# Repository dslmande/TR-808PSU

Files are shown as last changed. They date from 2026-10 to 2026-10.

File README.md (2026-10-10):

# TR-808PSU

> ## ⚠️ UNTESTED
>
> **This board has not been manufactured, assembled or tested.** It has not been checked
> against the real unit, and it has not been tested against any safety standard. The design
> is a copy of a historical (1984–86) circuit board. It is connected to **mains voltage
> (230 V, or 110 V for the second variant)**, which can kill. Use at your own risk, and only if you know what you are doing.
> Dimensions are derived from a scan (±3 %), see [VERIFICATION.md](VERIFICATION.md).

KiCad rebuild of the power supply board **PS3116 (PCB 291-405A)** of the Roland TR-808:
schematic redrawn from the 1981 service manual, board with outline, holes, terminals and
component positions taken from the original component layout. Two variants of the same board:

| Variant | Original board | Mains | Transformer | Files |
|---|---|---|---|---|
| **230 V** | PS3116-054 | 220/240 V | N-219D | `TR-808PSU_Rev0.5*` |
| **110 V** | PS3116-051 | 100/117 V (built for 110 V, 117 V tap) | N-218C | `TR-808PSU_Rev0.5-110V*` |

Both use the same copper; they differ in parts (fuses, transformer, switch, C1) and in the
silkscreen mark (`PS3116-054  230V` / `PS3116-051  110V`), so the boards cannot be mixed up.
Current version: **Rev0.5**.

| Version | Contents |
|---|---|
| [Rev0.1](https://github.com/dslmande/TR-808PSU/releases/tag/Rev0.1) | historical 1:1 copy of the 1984–86 original; switched mains conductors SW_A/SW_B 3.75 mm apart |
| [Rev0.2](https://github.com/dslmande/TR-808PSU/releases/tag/Rev0.2) | as Rev0.1, but SW_B moved away on the mains side: SW_A/SW_B at least 5.67 mm apart |
| [Rev0.3](https://github.com/dslmande/TR-808PSU/releases/tag/Rev0.3) | as Rev0.2, but the 230 V primary side (terminals 1–9: mains, switch, transformer input) uses **RM5.0 screw terminals** (Phoenix MKDS 1,5) instead of solder lugs; terminals 10–22 (low voltage) stay solder lugs |
| [Rev0.4](https://github.com/dslmande/TR-808PSU/releases/tag/Rev0.4) / [Rev0.4-110V](https://github.com/dslmande/TR-808PSU/releases/tag/Rev0.4-110V) | as Rev0.3, but all board corners rounded to R5 (house rule), voltage mark on the silkscreen; the 110 V variant is new (fuses 0.5 A, transformer N-218C) |
| **Rev0.5** / **Rev0.5-110V** (current) | as Rev0.4, but the voltage mark moved to the free area below the fuse holders (it touched the F4 outline). Two releases: 230 V and 110 V |

## Pictures (230 V)

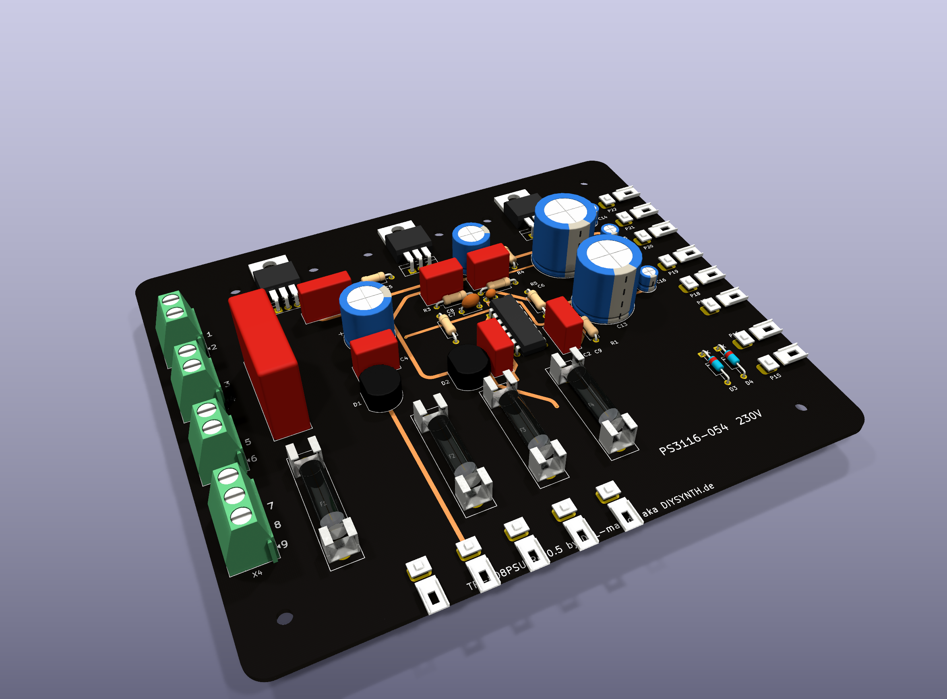
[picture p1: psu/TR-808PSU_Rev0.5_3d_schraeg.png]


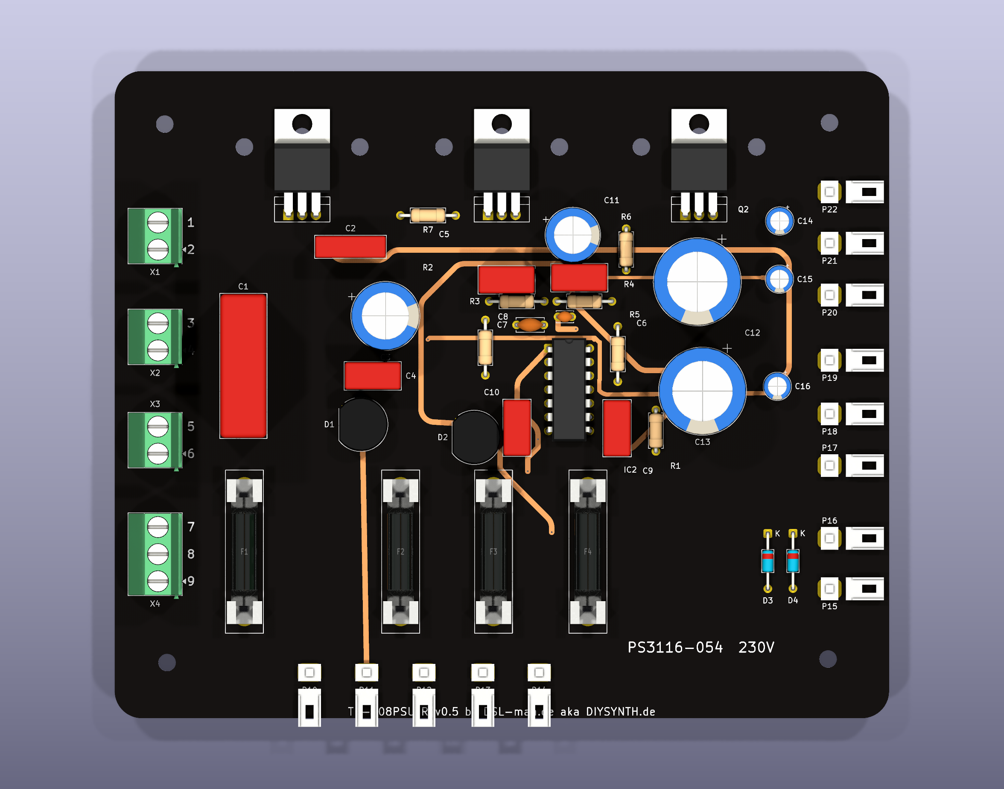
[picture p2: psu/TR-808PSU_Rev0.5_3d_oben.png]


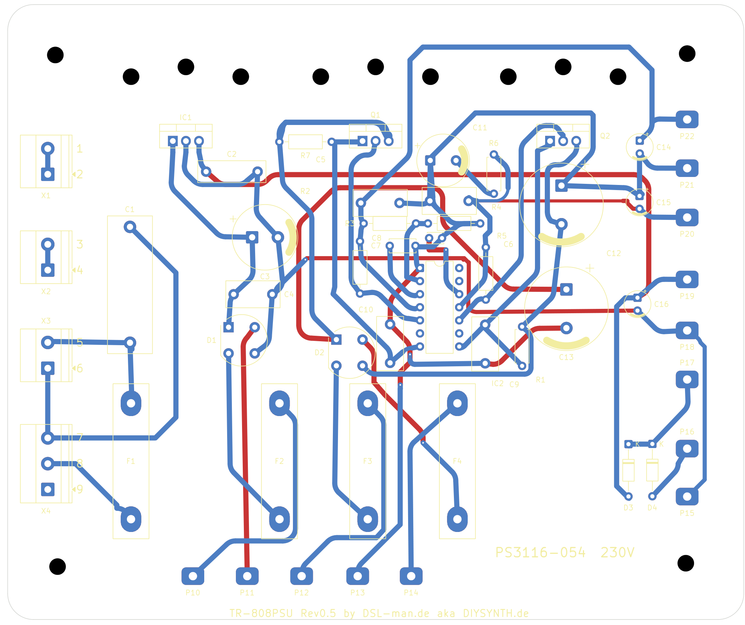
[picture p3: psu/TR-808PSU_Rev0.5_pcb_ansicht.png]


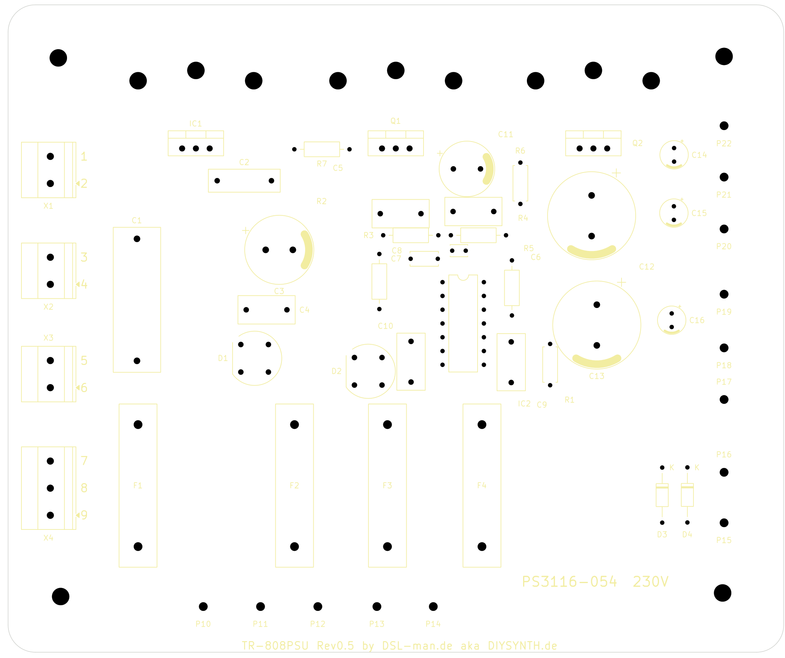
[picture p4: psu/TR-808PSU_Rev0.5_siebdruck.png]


### 110 V variant

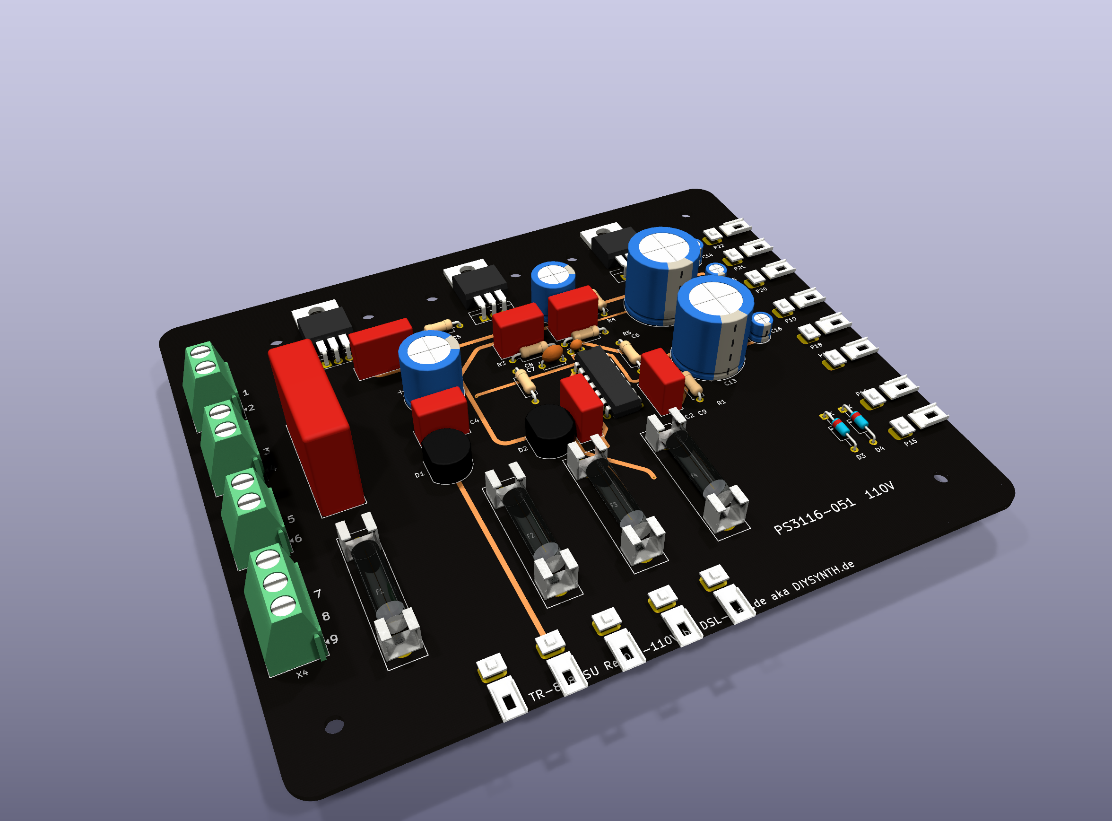
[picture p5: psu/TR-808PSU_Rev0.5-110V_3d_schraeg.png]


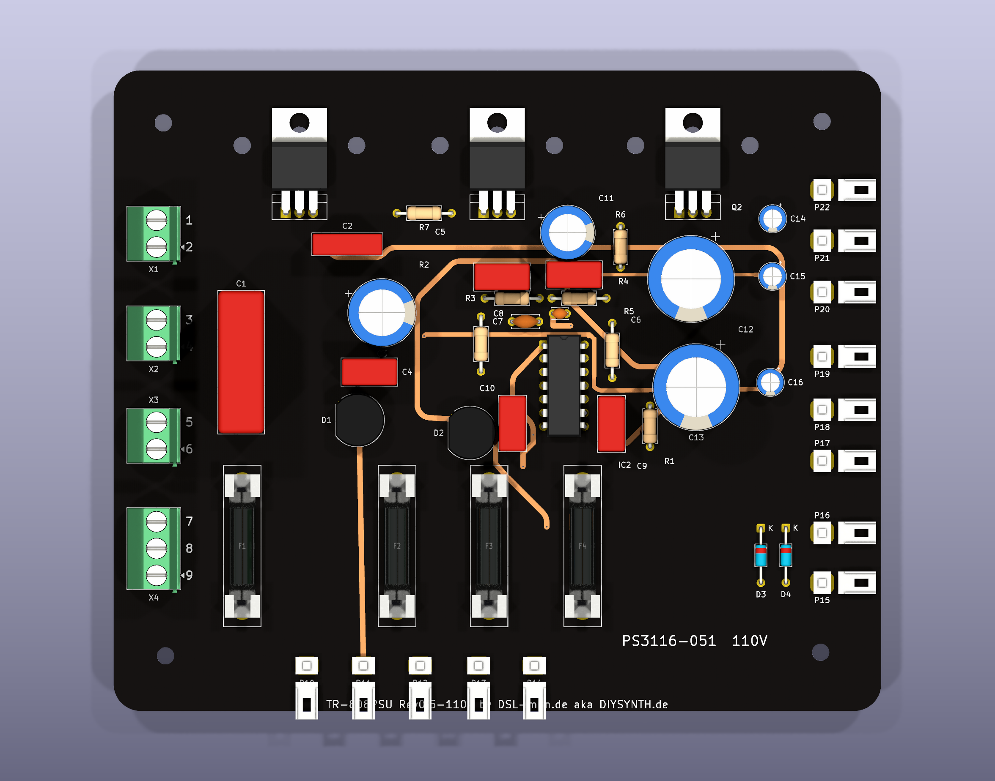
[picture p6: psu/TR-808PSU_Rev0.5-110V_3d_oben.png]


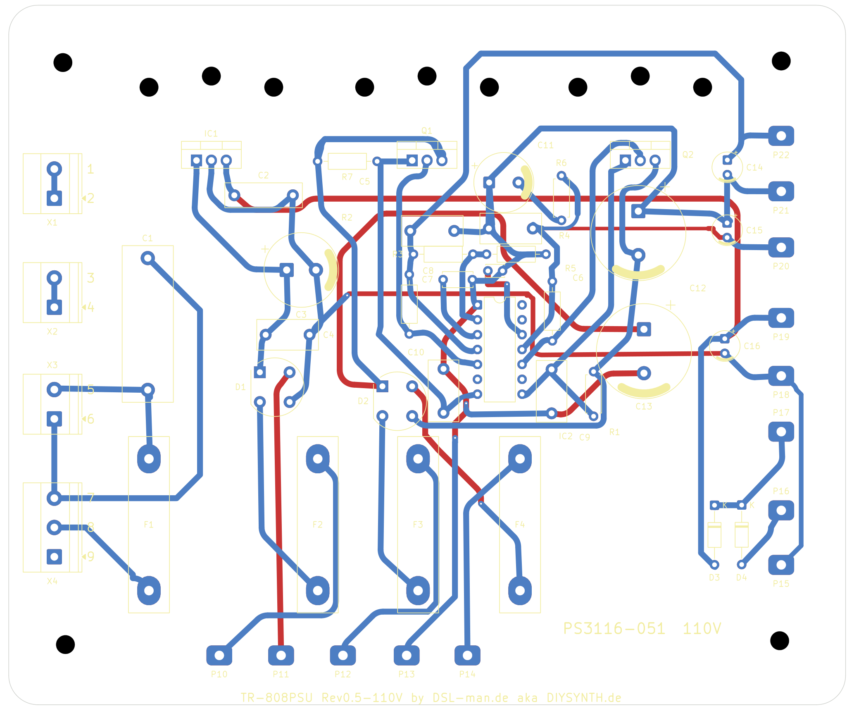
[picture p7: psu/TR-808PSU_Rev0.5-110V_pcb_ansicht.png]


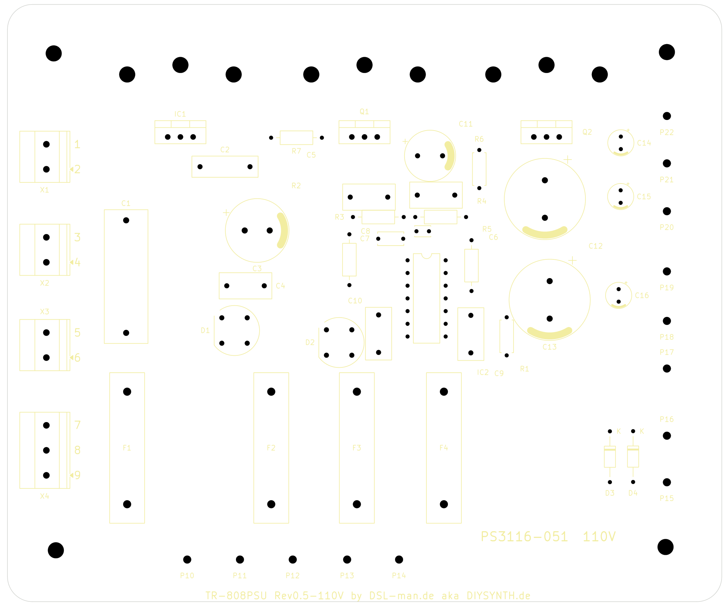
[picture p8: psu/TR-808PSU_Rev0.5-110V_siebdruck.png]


More (230 V; for 110 V use the `Rev0.5-110V` files, [BOM-110V.md](BOM-110V.md)): [schematic (PDF)](psu/TR-808PSU_Rev0.5_schaltplan.pdf) · [bill of materials](BOM.md) ([CSV](psu/TR-808PSU_Rev0.5_bom.csv)) · [1:1 printout (A4)](psu/TR-808PSU_Rev0.5_ausdruck_1zu1.pdf) · [Gerber (zip)](psu/TR-808PSU_Rev0.5_gerber.zip) · [assembly drawing (PDF)](psu/TR-808PSU_Rev0.5_assembly.pdf) · [original copper vs. tracks](psu/TR-808PSU_Rev0.5_ueberlagerung.png) · [verification](VERIFICATION.md) · [releases](https://github.com/dslmande/TR-808PSU/releases)

## Files

| File | Contents |
|---|---|
| [ORIGINAL.md](ORIGINAL.md) | source, manual pages, variants, circuit description, open points |
| [VERIFICATION.md](VERIFICATION.md) | standards context (DIN EN IEC 62368-1, IEC 60664-1), verification, validation, findings, risks |
| [BOM.md](BOM.md) / [BOM-110V.md](BOM-110V.md), `psu/TR-808PSU_Rev0.5_bom.csv` | bill of materials (readable, with function and original parts; CSV) |
| `psu/TR-808PSU_Rev0.5.kicad_pro` / `.kicad_sch` / `.kicad_pcb` (and `…Rev0.5-110V…`) | KiCad project |
| `psu/TR-808PSU_Rev0.5_schaltplan.pdf` | schematic plot |
| `psu/gerber_TR-808PSU_Rev0.5/`, `psu/TR-808PSU_Rev0.5_gerber.zip` | Gerber, drill data, position file |
| `psu/TR-808PSU_Rev0.5_ausdruck_1zu1.pdf` | 1:1 printout on A4 landscape: component side, solder side, drill template (print at 100 %, check the measuring bar) |
| `psu/TR-808PSU_Rev0.5_3d_oben.png`, `_3d_schraeg.png` | 3D views (KiCad ray tracing; own models for fuse holders and terminal lugs) |
| `psu/TR-808PSU_Rev0.5_pcb_top.pdf`, `_pcb_bottom.pdf`, `_assembly.pdf` | board plots |
| `psu/placement.json`, `psu/placement_scan.json` | component positions from the component layout, resp. aligned to the scan (mm) |
| `psu/kupfer.npz`, `psu/leitkarte.npz` | copper mask and net regions of the original (from the scan) |
| `psu/TR-808PSU_Rev0.5_ueberlagerung.png` | original copper against the tracks of this board |

File names with `schaltplan`, `ausdruck`, `kupfer` and `leitkarte` are German for schematic, printout, copper and guide map.

## What "1:1" means here

* **Circuit:** designators (C1–C16, R1–R7, D1–D4, F1–F4, Q1, Q2, IC1, IC2), values and
  terminal numbers 1–22 as in the original. The schematic is drawn like the original
  (mains and switch left, transformer, +5 V branch, ±15 V branch).
* **Board:** outline (from Rev0.5 with R5 corners instead of the sharp corners of the original), four mounting holes, six heat sink holes (one pair per regulator,
  21.3 mm apart, centred) and three M3 screw holes for the regulators, RM5 screw terminals
  (terminals 1–9), terminal pins (10–22), fuse clips and all components at the positions of
  the original, fine-tuned to the copper of the scan. The original is single
  sided with one wire jumper; this rebuild is two-layer.
* **Tracks: guided by the original, not copied one to one.** The copper of the original is
  extracted from the scan (halftone → mask → net regions) and used as a cost map by the
  router: original copper is cheap, everything else is expensive, the component side is
  almost blocked. The result is a DRC-clean board that follows the original where the scan
  allows. **37 % of the track length lies on original copper**, the rest is routed anew
  (wide tracks and smoothing move the paths away from the original);
  `psu/TR-808PSU_Rev0.5_ueberlagerung.png` shows the original copper (grey) and the tracks
  (red solder side, blue component side). Pure tracing without the router fails because of
  the scan quality (shorts between neighbouring tracks, pad positions only within ±0.3 mm).
* **Dimensions** are derived from the component layout (the manual has no scale), tolerance
  about ±3 %. Measure against a real board before manufacturing. Details and further open
  points in [ORIGINAL.md](ORIGINAL.md).

## Status (Rev0.5, 10 Oct 2026; both variants)

* **ERC:** 0 violations (`psu/TR-808PSU_Rev0.5-erc.rpt`).
* **DRC (clearance rule 0.25 mm):** 0 errors; warnings only (4 courtyard overlaps, 1
  silkscreen overlap, 7 footprint deviations from the library because of the polarity bars);
  0 unconnected items; schematic/board parity 0.
* **Mains against low voltage:** more than 8 mm copper to copper;
  between the mains conductors 4.0–5.67 mm, adjacent terminal poles 2.4 mm (RM5 pitch).
* **Netlist against the schematic:** read by hand from the schematic and checked against the
  plot; no independent comparison, see "Open" in [ORIGINAL.md](ORIGINAL.md).
* Track width 1.0 mm throughout; hairpins and stubs in pads are
  removed; smoothed (45°, arcs). No copper pours, as in the original. Five
  vias; most of the copper is on the solder side, about 440 mm of track on the component side
  (the original used the wire jumper J1 for this).
* **Silkscreen:** designators only (no values), terminal numbers 1–9 next to the screw
  terminals and P10–P22 on the pins, electrolytic polarity as a bar at the minus side as in
  the original, the four fuse holders F1–F4 on one line.
* **Not done:** assembly and measurement on the unit, manufacturing, any safety testing.

## Rebuilding

Schematic and layout were generated with a private tool chain that is not part of this
repo. The KiCad project in `psu/` is complete and needs only KiCad 9/10.

## License

Hardware files (KiCad project, Gerber, schematic, documents):
[CERN-OHL-W-2.0](LICENSE) (CERN Open Hardware Licence v2, weakly reciprocal). The licence
covers only this redrawing and layout, not Roland's original design or manual. Provided as is, without
warranty: see the disclaimer in the licence and the UNTESTED notice above.

## Source and rights

Circuit and dimensions come from the Roland TR-808 service manual (15 June 1981). The manual
itself and the data sheets are not part of this repo (copyright of Roland and the
manufacturers). This repo contains an own redrawing for repair and rebuild. "Roland" and
"TR-808" are trademarks of Roland Corporation; this project is not affiliated with Roland.

Data sheets used to check the pin assignments: 2SB596 (MOSPEC), 2SD880 (DC Components),
TA7179P and µA7805 (service manual, page 2).

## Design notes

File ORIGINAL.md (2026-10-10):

# The original: power supply board PS3116 of the Roland TR-808

> **UNTESTED.** This describes how the rebuild relates to the original; nothing here was
> verified on a real unit. See [VERIFICATION.md](VERIFICATION.md).

Source is the service manual "TR-808 Service Notes" (Roland, 15 June 1981, 3rd printing),
archive.org scan `Roland_TR-808_Service_Manual.pdf` (MD5 `77ac6c77c9e0d92ea67b2021ecc97623`,
16 pages). The manual is not part of this repo; to check the work, download it yourself and
put it under `vorlage/` (German for "template"; excluded there by `.gitignore`).

| Sheet | Contents | Used for |
|---|---|---|
| 2 | pin assignments (TA7179P, µA7805) | symbols IC2, IC1 |
| 10 | parts list | component types, board numbers |
| 12 | component layout POWER SUPPLY PS3116-051/-054, PCB 291-405A | board outline, component positions |
| 13 | schematic (top left: POWER SUPPLY) | schematic |
| 15 | design changes | read, does not concern the power supply |

## Variants

The board is the same for all mains voltages; only the fitting and accessories differ:

| Mains | Board | T1 | Switch | C1 | Fuses F1–F4 |
|---|---|---|---|---|---|
| 100 V | PS3116-051 | N-217N | SDG5P-001 | ECQ-UC1A473MC | SGA 0.5 A |
| 117 V | PS3116-051 | N-218C | SDG5P-001 | ECQ-UC1A473MC | SGA 0.5 A |
| 220 V | PS3116-054 | N-219D | SDG5P-502 | ECQ-U2A473MF | CEE 250 mAT |
| 240 V | PS3116-054 | N-219D | SDG5P-502 | ECQ-U2A473MF | CEE 250 mAT |

**This repo models both: the 220/240 V variant (PS3116-054, files `Rev0.5`) and, from Rev0.5,
the 100/117 V variant (PS3116-051) built for 110 V (files `Rev0.5-110V`, transformer N-218C,
117 V tap; 110 V is 6 % below its rating).** Only parts change (C1, F1–F4, T1, switch); the copper
is identical. The schematic of each variant carries its own values. According to the manual F2 and F3 are
fitted differently on late 100/117 V units; the note in the plan is hard to read at that
spot, see "Open".

## Circuit

* **Mains:** terminals 3 (W1) and 1 (W3) are the mains lead. 3 and 4, and 1 and 2, are
  connected on the board. The mains switch (two poles, not on the board) connects 4–5 and
  2–6. C1 (47 nF, interference suppression) sits between 5 and 6, F1 from the switch to
  terminal 8. T1 connects to 7, 8, 9 (primary) and 10–14 (secondary).
* **+5 V:** winding yellow–yellow (10, 11) → F2 → bridge D1 → C3 1000 µ/16, C4 100 n → IC1
  µA7805 → +5 V. C2 100 n and C16 10 µ at the output. Terminal 19 is +5 V, 15 and 18 are the
  5 V ground.
* **RAM backup:** D3 (1S2473) from +5 V, D4 (1S2473) from the 3 × 1.5 V battery (terminal 16,
  minus at 15), both cathodes to terminal 17.
* **±15 V:** winding red–black–red (12, 13 centre tap, 14) → F3/F4 → bridge D2 → C13, C12
  1000 µ/35 each → ±23 V. IC2 TA7179P (dual tracking regulator) with the pass transistors
  Q1 2SB596 (+) and Q2 2SD880 (−), a 47 Ω base resistor each (R7, R1) with 100 n (C10, C9),
  3.3 Ω current limit (R2, R5), divider R3/R4 15 k, C7/C8 10 n compensation. Outputs +15 V
  (22), 0 V (21), −15 V (20). C5, C14, C6, C15 smoothing, C11 470 µ/16 with R6 220 Ω as load.
* **Secondary voltages according to the plan at 0.15 A DC:** 10 V (yellow–yellow), 23 V per
  half (red–black).

## What the rebuild changes

* The original is **single sided** (wire jumper J1). This rebuild is **two-layer**, the
  jumper is dropped; board outline, holes, terminals and component positions follow the
  component layout and are adjusted to the scan copper; the tracks **follow the original
  copper only to 37 %** (router with a cost map from the scan, see the README), the rest is
  routed anew.
* The two grounds (5 V branch: terminals 15/18; ±15 V branch: 13/21) are **not** connected
  in the plan and are not connected here either. They meet only outside the board, probably
  on the main board.
* Transformer T1, mains switch and battery are not on the board (from Rev0.3 mains, switch
  and transformer input use RM5 screw terminals instead of solder lugs) and appear in the
  schematic only as external symbols.
* Bridges D1/D2: **W04** (400 V; the unit shows 2W04G) instead of W-02 (200 V) from the
  manual. The W04 is a permissible replacement in the same package.

## Open / not proven

* **Scale:** the component layout has no scale bar. The scale (0.544 mm per pt) is derived
  from the TO-220 lead pitch (2.54 mm) and the DIP-14; the board is 142.9 × 119.4 mm, with a
  tolerance of roughly ±3 %. Measure against a real board before manufacturing (holes of the
  heat sink 246-101A, distance of the fuse clips 22.5 mm).
* **Labelling in the component layout deviates from the schematic** at R1/R7 and C9/C10 (the
  assignment to Q1/Q2 is swapped). The netlist follows the schematic; the parts sit by
  function in the layout.
* **Lead spacing of the parts** (resistors, film capacitors) was chosen from the scan copper
  (pads must lie on copper pieces that carry only one net), not from the manual; four copper
  pieces still show a net conflict in the fit (AC15_A/AC15_RAW_A and others, probably
  connected copper because of the scan quality). The manual gives no package types.
* **Packages:** bridge as a round package ø 9.8 mm (Vishay WOG), electrolytics by measured
  diameter; the manual gives no package types.
* Pin assignment of 2SB596 / 2SD880: B-C-E (MOSPEC resp. DC Components data sheets, from
  archive.org/distributors, not in the repo).
* The footnote on the fuses ("F2–F3 on later 100/117V versions … 10 ohm 1/4W (fusing
  resistor)") is cut off in the scan and not clearly legible.

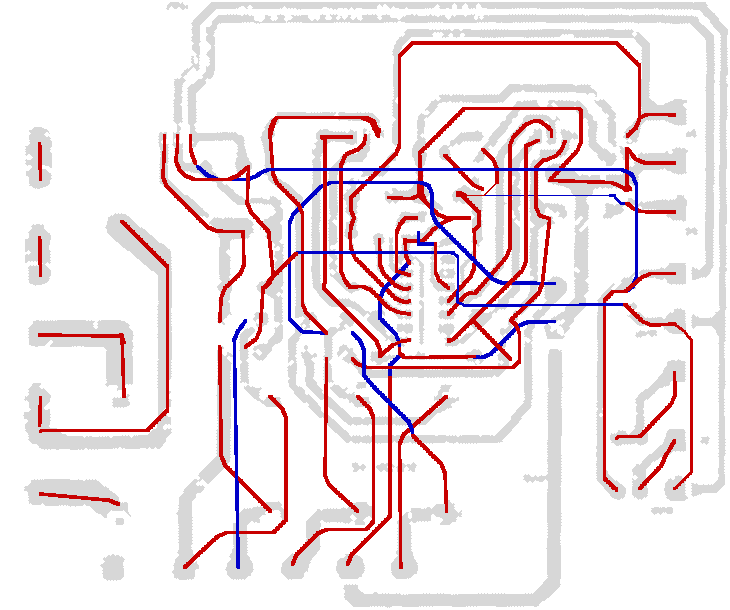
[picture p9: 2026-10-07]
psu/TR-808PSU_Rev0.5_ueberlagerung.png

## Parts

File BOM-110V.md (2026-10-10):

# Bill of materials TR-808PSU Rev0.5-110V

> **UNTESTED.** Nothing here has been ordered, built or measured.

Generated from the schematic (`psu/TR-808PSU_Rev0.5-110V_bom.csv`). **No prices, no suppliers:** none of that is checked.
Parts of the power supply per the service manual (PS3116-051, 100/117 V, built for 110 V); the "Remark" column names the original part where the manual gives one.

| Designators | Qty | Value | Function | Package (KiCad) | Remark |
|---|---|---|---|---|---|
| C1 | 1 | 0.047u/X2 | Interference suppression capacitor, 100/117 V | `C_Rect_L26.5mm_W8.5mm_P22.50mm_MKS4` | Original ECQ-UC1A473MC (Panasonic), 47 nF; 110 V: X2 type is also fine |
| C2 | 1 | 0.1u | Decoupling +5 V | `C_Rect_L13.0mm_W4.0mm_P10.00mm_FKS3_FKP3_MKS4` | 100 nF film |
| C3 | 1 | 1000u/16V | Smoothing 5 V branch | `CP_Radial_D12.5mm_P5.00mm` | 1000 µF / 16 V electrolytic |
| C4, C5, C6, C9, C10 | 5 | 0.1u | Decoupling / smoothing | `C_Rect_L10.3mm_W5.0mm_P7.50mm_MKS4` | 100 nF film, 7.5 mm pitch |
| C7 | 1 | 0.01u | Compensation TA7179P pin 3 | `C_Disc_D5.0mm_W2.5mm_P5.00mm` | 10 nF |
| C8 | 1 | 0.01u | Compensation TA7179P pin 12 | `C_Disc_D3.0mm_W2.0mm_P2.50mm` | 10 nF |
| C11 | 1 | 470u/16V | Load ±15 V with R6 | `CP_Radial_D10.0mm_P5.00mm` | 470 µF / 16 V electrolytic |
| C12, C13 | 2 | 1000u/35V | Smoothing ±23 V | `CP_Radial_D16.0mm_P7.50mm` | 1000 µF / 35 V electrolytic |
| C14, C15, C16 | 3 | 10u/16V | Output smoothing | `CP_Radial_D5.0mm_P2.50mm` | 10 µF / 16 V electrolytic |
| D1, D2 | 2 | W04 | Bridge rectifier, round | `Diode_Bridge_Round_D9.8mm` | Manual: W-02 (200 V); fitted/replacement: W04 (2W04G, 400 V) |
| D3, D4 | 2 | 1S2473 | RAM backup diodes | `D_DO-35_SOD27_P10.16mm_Horizontal` | 1S2473 (Si diode); replacement e.g. 1N4148 – not checked |
| F1, F2, F3, F4 | 4 | 0.5A | Miniature fuses 5×20 mm | `FuseClip_5x20_TF785` | SGA 0.5 A (100/117 V); clips TF785, 22.5 mm apart; fuse type per original, not checked |
| IC1 | 1 | uA7805 | 5 V regulator | `TO-220-3_Vertical` | µA7805UC, TO-220, lying on the heat sink angle |
| IC2 | 1 | TA7179P | Dual ±15 V tracking regulator | `DIP-14_W7.62mm` | TA7179P (Toshiba), DIP-14 – probably discontinued, availability not checked |
| P10 | 1 | 10 |  | `Terminal_Pin` |  |
| P11 | 1 | 11 |  | `Terminal_Pin` |  |
| P12 | 1 | 12 |  | `Terminal_Pin` |  |
| P13 | 1 | 13 |  | `Terminal_Pin` |  |
| P14 | 1 | 14 |  | `Terminal_Pin` |  |
| P15 | 1 | 15 |  | `Terminal_Pin` |  |
| P16 | 1 | 16 |  | `Terminal_Pin` |  |
| P17 | 1 | 17 |  | `Terminal_Pin` |  |
| P18 | 1 | 18 |  | `Terminal_Pin` |  |
| P19 | 1 | 19 |  | `Terminal_Pin` |  |
| P20 | 1 | 20 |  | `Terminal_Pin` |  |
| P21 | 1 | 21 |  | `Terminal_Pin` |  |
| P22 | 1 | 22 |  | `Terminal_Pin` |  |
| Q1 | 1 | 2SB596 | Pass transistor +15 V | `TO-220-3_Vertical` | 2SB596 (PNP, TO-220) |
| Q2 | 1 | 2SD880 | Pass transistor −15 V | `TO-220-3_Vertical` | 2SD880 (NPN, TO-220) |
| R1 | 1 | 47 | Base resistor Q2 | `R_Axial_DIN0207_L6.3mm_D2.5mm_P7.62mm_Horizontal` | 47 Ω |
| R2, R5 | 2 | 3.3 | Current limit | `R_Axial_DIN0207_L6.3mm_D2.5mm_P10.16mm_Horizontal` | 3.3 Ω |
| R3, R4 | 2 | 15k | Voltage divider | `R_Axial_DIN0207_L6.3mm_D2.5mm_P10.16mm_Horizontal` | 15 kΩ |
| R6 | 1 | 220 | Load ±15 V with C11 | `R_Axial_DIN0207_L6.3mm_D2.5mm_P7.62mm_Horizontal` | 220 Ω |
| R7 | 1 | 47 | Base resistor Q1 | `R_Axial_DIN0207_L6.3mm_D2.5mm_P10.16mm_Horizontal` | 47 Ω |
| X1, X2, X3 | 3 | 2P RM5 | Screw terminals mains (110 V), 2 poles | `TerminalBlock_Phoenix_MKDS-1,5-2_1x02_P5.00mm_Horizontal` | Phoenix MKDS 1,5/2-5,00 (5.0 mm pitch) |
| X4 | 1 | 3P RM5 | Screw terminal mains (110 V), 3 poles | `TerminalBlock_Phoenix_MKDS-1,5-3_1x03_P5.00mm_Horizontal` | Phoenix MKDS 1,5/3-5,00 (5.0 mm pitch) |
|  | 0 | solder lug | terminals 10–22 (low voltage) | `Terminal_Pin` (own design) | original: solder lugs; hole 1.6 mm, pad 4.4 × 3.4 mm |

## Not in the bill of materials (mechanical / external)

- **Mains transformer T1:** connected through terminals 7–9 (primary) and 10–14 (secondary); original N-218C (117 V), not on the board; 110 V is 6 % below its rating.
- **Mains switch SW1** (two poles, SDG5P-001 for 100/117 V) and **battery 3 × 1.5 V** (between 15 and 16): external.
- **Heat sink 246-101A** (aluminium angles, three pieces) with M3 screws: 6 holes for the angles plus three screw holes for the regulators.
- **Mounting:** four M3 holes at the board corners.

## Parts at risk

TA7179P, 2SB596, 2SD880 and the 1S2473 are early-1980s parts; with rebuilds of old units such types are often discontinued and affected by counterfeits. Before ordering, check them via the Mouser/TME API and settle a replacement for IC2 (see [VERIFICATION.md](VERIFICATION.md)).

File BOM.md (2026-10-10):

# Bill of materials TR-808PSU Rev0.5

> **UNTESTED.** Nothing here has been ordered, built or measured.

Generated from the schematic (`psu/TR-808PSU_Rev0.5_bom.csv`). **No prices, no suppliers:** none of that is checked.
Parts of the power supply per the service manual (PS3116-054, 220/240 V); the "Remark" column names the original part where the manual gives one.

| Designators | Qty | Value | Function | Package (KiCad) | Remark |
|---|---|---|---|---|---|
| C1 | 1 | 0.047u/X2 | Interference suppression capacitor X2, 220/240 V | `C_Rect_L26.5mm_W8.5mm_P22.50mm_MKS4` | Original ECQ-U2A473MF (Panasonic), 47 nF, 275 V~ |
| C2 | 1 | 0.1u | Decoupling +5 V | `C_Rect_L13.0mm_W4.0mm_P10.00mm_FKS3_FKP3_MKS4` | 100 nF film |
| C3 | 1 | 1000u/16V | Smoothing 5 V branch | `CP_Radial_D12.5mm_P5.00mm` | 1000 µF / 16 V electrolytic |
| C4, C5, C6, C9, C10 | 5 | 0.1u | Decoupling / smoothing | `C_Rect_L10.3mm_W5.0mm_P7.50mm_MKS4` | 100 nF film, 7.5 mm pitch |
| C7 | 1 | 0.01u | Compensation TA7179P pin 3 | `C_Disc_D5.0mm_W2.5mm_P5.00mm` | 10 nF |
| C8 | 1 | 0.01u | Compensation TA7179P pin 12 | `C_Disc_D3.0mm_W2.0mm_P2.50mm` | 10 nF |
| C11 | 1 | 470u/16V | Load ±15 V with R6 | `CP_Radial_D10.0mm_P5.00mm` | 470 µF / 16 V electrolytic |
| C12, C13 | 2 | 1000u/35V | Smoothing ±23 V | `CP_Radial_D16.0mm_P7.50mm` | 1000 µF / 35 V electrolytic |
| C14, C15, C16 | 3 | 10u/16V | Output smoothing | `CP_Radial_D5.0mm_P2.50mm` | 10 µF / 16 V electrolytic |
| D1, D2 | 2 | W04 | Bridge rectifier, round | `Diode_Bridge_Round_D9.8mm` | Manual: W-02 (200 V); fitted/replacement: W04 (2W04G, 400 V) |
| D3, D4 | 2 | 1S2473 | RAM backup diodes | `D_DO-35_SOD27_P10.16mm_Horizontal` | 1S2473 (Si diode); replacement e.g. 1N4148 – not checked |
| F1, F2, F3, F4 | 4 | 250mAT | Miniature fuses 5×20 mm | `FuseClip_5x20_TF785` | T250 mA / 250 V (CEE, 220/240 V); clips TF785, 22.5 mm apart |
| IC1 | 1 | uA7805 | 5 V regulator | `TO-220-3_Vertical` | µA7805UC, TO-220, lying on the heat sink angle |
| IC2 | 1 | TA7179P | Dual ±15 V tracking regulator | `DIP-14_W7.62mm` | TA7179P (Toshiba), DIP-14 – probably discontinued, availability not checked |
| P10 | 1 | 10 |  | `Terminal_Pin` |  |
| P11 | 1 | 11 |  | `Terminal_Pin` |  |
| P12 | 1 | 12 |  | `Terminal_Pin` |  |
| P13 | 1 | 13 |  | `Terminal_Pin` |  |
| P14 | 1 | 14 |  | `Terminal_Pin` |  |
| P15 | 1 | 15 |  | `Terminal_Pin` |  |
| P16 | 1 | 16 |  | `Terminal_Pin` |  |
| P17 | 1 | 17 |  | `Terminal_Pin` |  |
| P18 | 1 | 18 |  | `Terminal_Pin` |  |
| P19 | 1 | 19 |  | `Terminal_Pin` |  |
| P20 | 1 | 20 |  | `Terminal_Pin` |  |
| P21 | 1 | 21 |  | `Terminal_Pin` |  |
| P22 | 1 | 22 |  | `Terminal_Pin` |  |
| Q1 | 1 | 2SB596 | Pass transistor +15 V | `TO-220-3_Vertical` | 2SB596 (PNP, TO-220) |
| Q2 | 1 | 2SD880 | Pass transistor −15 V | `TO-220-3_Vertical` | 2SD880 (NPN, TO-220) |
| R1 | 1 | 47 | Base resistor Q2 | `R_Axial_DIN0207_L6.3mm_D2.5mm_P7.62mm_Horizontal` | 47 Ω |
| R2, R5 | 2 | 3.3 | Current limit | `R_Axial_DIN0207_L6.3mm_D2.5mm_P10.16mm_Horizontal` | 3.3 Ω |
| R3, R4 | 2 | 15k | Voltage divider | `R_Axial_DIN0207_L6.3mm_D2.5mm_P10.16mm_Horizontal` | 15 kΩ |
| R6 | 1 | 220 | Load ±15 V with C11 | `R_Axial_DIN0207_L6.3mm_D2.5mm_P7.62mm_Horizontal` | 220 Ω |
| R7 | 1 | 47 | Base resistor Q1 | `R_Axial_DIN0207_L6.3mm_D2.5mm_P10.16mm_Horizontal` | 47 Ω |
| X1, X2, X3 | 3 | 2P RM5 | Screw terminals mains (230 V), 2 poles | `TerminalBlock_Phoenix_MKDS-1,5-2_1x02_P5.00mm_Horizontal` | Phoenix MKDS 1,5/2-5,00 (5.0 mm pitch) |
| X4 | 1 | 3P RM5 | Screw terminal mains (230 V), 3 poles | `TerminalBlock_Phoenix_MKDS-1,5-3_1x03_P5.00mm_Horizontal` | Phoenix MKDS 1,5/3-5,00 (5.0 mm pitch) |
|  | 0 | solder lug | terminals 10–22 (low voltage) | `Terminal_Pin` (own design) | original: solder lugs; hole 1.6 mm, pad 4.4 × 3.4 mm |

## Not in the bill of materials (mechanical / external)

- **Mains transformer T1:** connected through terminals 7–9 (primary) and 10–14 (secondary); original N-219D (220/240 V), not on the board.
- **Mains switch SW1** (two poles) and **battery 3 × 1.5 V** (between 15 and 16): external.
- **Heat sink 246-101A** (aluminium angles, three pieces) with M3 screws: 6 holes for the angles plus three screw holes for the regulators.
- **Mounting:** four M3 holes at the board corners.

## Parts at risk

TA7179P, 2SB596, 2SD880 and the 1S2473 are early-1980s parts; with rebuilds of old units such types are often discontinued and affected by counterfeits. Before ordering, check them via the Mouser/TME API and settle a replacement for IC2 (see [VERIFICATION.md](VERIFICATION.md)).

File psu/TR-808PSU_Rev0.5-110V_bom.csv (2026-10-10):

Reference | Value | Footprint | QUANTITY
C1 | 0.047u/X2 | Capacitor_THT:C_Rect_L26.5mm_W8.5mm_P22.50mm_MKS4 | 1
C2 | 0.1u | Capacitor_THT:C_Rect_L13.0mm_W4.0mm_P10.00mm_FKS3_FKP3_MKS4 | 1
C3 | 1000u/16V | Capacitor_THT:CP_Radial_D12.5mm_P5.00mm | 1
C4,C5,C6,C9,C10 | 0.1u | Capacitor_THT:C_Rect_L10.3mm_W5.0mm_P7.50mm_MKS4 | 5
C7 | 0.01u | Capacitor_THT:C_Disc_D5.0mm_W2.5mm_P5.00mm | 1
C8 | 0.01u | Capacitor_THT:C_Disc_D3.0mm_W2.0mm_P2.50mm | 1
C11 | 470u/16V | Capacitor_THT:CP_Radial_D10.0mm_P5.00mm | 1
C12,C13 | 1000u/35V | Capacitor_THT:CP_Radial_D16.0mm_P7.50mm | 2
C14,C15,C16 | 10u/16V | Capacitor_THT:CP_Radial_D5.0mm_P2.50mm | 3
D1,D2 | W04 | Diode_THT:Diode_Bridge_Round_D9.8mm | 2
D3,D4 | 1S2473 | Diode_THT:D_DO-35_SOD27_P10.16mm_Horizontal | 2
F1,F2,F3,F4 | 0.5A | TR808PSU:FuseClip_5x20_TF785 | 4
IC1 | uA7805 | Package_TO_SOT_THT:TO-220-3_Vertical | 1
IC2 | TA7179P | Package_DIP:DIP-14_W7.62mm | 1
P10 | 10 | TR808PSU:Terminal_Pin | 1
P11 | 11 | TR808PSU:Terminal_Pin | 1
P12 | 12 | TR808PSU:Terminal_Pin | 1
P13 | 13 | TR808PSU:Terminal_Pin | 1
P14 | 14 | TR808PSU:Terminal_Pin | 1
P15 | 15 | TR808PSU:Terminal_Pin | 1
P16 | 16 | TR808PSU:Terminal_Pin | 1
P17 | 17 | TR808PSU:Terminal_Pin | 1
P18 | 18 | TR808PSU:Terminal_Pin | 1
P19 | 19 | TR808PSU:Terminal_Pin | 1
P20 | 20 | TR808PSU:Terminal_Pin | 1
P21 | 21 | TR808PSU:Terminal_Pin | 1
P22 | 22 | TR808PSU:Terminal_Pin | 1
Q1 | 2SB596 | Package_TO_SOT_THT:TO-220-3_Vertical | 1
Q2 | 2SD880 | Package_TO_SOT_THT:TO-220-3_Vertical | 1
R1 | 47 | Resistor_THT:R_Axial_DIN0207_L6.3mm_D2.5mm_P7.62mm_Horizontal | 1
R2,R5 | 3.3 | Resistor_THT:R_Axial_DIN0207_L6.3mm_D2.5mm_P10.16mm_Horizontal | 2
R3,R4 | 15k | Resistor_THT:R_Axial_DIN0207_L6.3mm_D2.5mm_P10.16mm_Horizontal | 2
R6 | 220 | Resistor_THT:R_Axial_DIN0207_L6.3mm_D2.5mm_P7.62mm_Horizontal | 1
R7 | 47 | Resistor_THT:R_Axial_DIN0207_L6.3mm_D2.5mm_P10.16mm_Horizontal | 1
X1,X2,X3 | 2P RM5 | TerminalBlock_Phoenix:TerminalBlock_Phoenix_MKDS-1,5-2_1x02_P5.00mm_Horizontal | 3
X4 | 3P RM5 | TerminalBlock_Phoenix:TerminalBlock_Phoenix_MKDS-1,5-3_1x03_P5.00mm_Horizontal | 1

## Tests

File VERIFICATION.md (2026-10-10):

# Verification against standards and acceptance criteria (Rev0.5, 10 Oct 2026)

> **UNTESTED.** Nothing on this page is a conformity statement. The board has not been
> manufactured or tested; the standards were researched only to see where a historical
> design differs from today's requirements.

**Context:** the original dates from 1984–86 (service manual, 3rd printing June 1986;
power supply board PS3116) and was never checked against today's safety standards. This
rebuild is a **1:1 copy of a historical design**. The standard values below are for
orientation: they show where the old design deviates from current requirements. They are
not acceptance criteria for the copy and no claim of conformity.

Approach, following the skill `regelwerk-auf-projekte-anwenden` (applying a rule set to the
real project): research the standard's current edition first, then tie it to the actual
inventory; separate verification (does it meet the specification?) from validation (does it
suit the purpose?). **No certification, no proof of conformity:** the board is a private
rebuild of a repair board; the standards texts are paid and were not available to me.

## Standards framework (researched)

| Subject | Standard | Status | Source |
|---|---|---|---|
| Safety of audio/video and IT equipment (replaces DIN EN 60065) | DIN EN IEC 62368-1 (VDE 0868-1) | edition 2024 + A11:2024, VDE 0868-1:2025-01 | [DIN EN IEC 62368-1:2024](https://ib-lenhardt.com/standards/din-en-iec-62368-1-2024-a11-2024), [testxchange](https://www.testxchange.com/pruefnorm/iecen-62368-1/) |
| Clearance and creepage, insulation coordination | IEC 60664-1 / DIN EN 60664-1 (VDE 0110-1) | table values not freely available; sources disagree (creepage at 250 V, pollution degree 2, material group III: 3.2 to 4 mm basic) | [Elektor part 1](https://elektormagazine.com/news/pcb-clearance-and-creepage-distances-1), [TI SLUP419](https://www.ti.com/lit/pdf/slup419) |
| Miniature fuses | DIN EN 60127 (T250mA/250V) | not checked |  |
| Interference suppression capacitor C1 | DIN EN 60384-14 (X2) | type per manual ECQ-U2A473MF, not checked |  |
| Printed boards | IPC-2221 / IPC-A-600 | not applied |  |

For a privately built part for one's own unit there is no CE marking obligation; anyone who
passes it on or sells it needs it. This is not legal advice.

## Verification (measured)

| Criterion | Result |
|---|---|
| ERC | 0 violations |
| DRC (rule 0.25 mm) | 0 errors, 0 unconnected, 0 schematic/board deviations |
| Mains against low voltage (copper to copper) | **more than 8 mm** (all mains nets against the 5 V and ±15 V nets) |
| Mains conductors against each other (SW_A against SW_B) | Rev0.3: tracks 4.0 to 5.67 mm, adjacent terminal poles 2.4 mm (RM5 pitch); Rev0.1 had 3.75 mm |
| Mains, terminal 8 against terminal 9 | 6.87 mm |
| Manufacturing | Gerber, drill and position data, 1:1 printout available |

The clearance measurement uses a temporary net class of 8 mm (the DRC reports every
shortfall). In Rev0.1 the two switched mains conductors were 3.75 mm apart: more than 2 mm
(basic-insulation clearance in the search hits) but **below 4 mm**, the most conservative
value found for creepage (material group III, pollution degree 2, 250 V). In Rev0.2 and
Rev0.3 they are at least 4.0 mm apart (tracks; 5.67 mm for SW_A/SW_B), mains against low
voltage is unchanged above 8 mm.

## Validation (not done yet)

These points can only be settled on the unit; no gate counts as passed while they are open:

1. **Scale:** the component layout has no scale bar (0.544 mm per pt, ±3 %). Measure against
   a real board (heat sink holes, fuse clips, terminal spacing).
2. **Under load:** measure +5 V, ±15 V and the RAM supply on an assembled supply (nominal
   values in the manual: 10 V DC from yellow–yellow, 23 V per half from red–black at 0.15 A DC).
3. **Supply in the unit:** does the board fit the TR-808 case, does the heat sink angle
   246-101A fit, do the terminals match the wiring (a photo of the real part is on hand).
4. **Insulation:** if the supply is passed on, high-voltage testing by a qualified person.

## Findings and non-conformities

| No. | Finding | Severity | Status |
|---|---|---|---|
| 1 | Rev0.1: SW_A/SW_B 3.75 mm; today's conservative value 4 mm (deviation of the historical design from today's standard) | medium | fixed in Rev0.2 |
| 2 | Bridges W04 instead of W-02 per manual (type on the real board: 2W04G) | low | deliberate, noted in ORIGINAL.md and in the schematic |
| 3 | Tracks follow the original copper only to 37 %; two-layer instead of single-sided | low | documented |
| 4 | Netlist read by hand from the schematic; 4 copper pieces with two nets in the scan fit | medium | open |
| 5 | 3D models for fuse holders and terminal lugs built by hand, dimensions estimated | low | documented |
| 6 | DRC warnings: 4 courtyards, 1 silkscreen, 7 footprint deviations (polarity bars) | low | deliberate |

## Risks (parts)

- **TA7179P** (Toshiba) and **2SB596/2SD880**: with rebuilds of old units it is the rule
  that key parts are discontinued; grey market means counterfeits. Before the first order,
  create a part check (stock and lifecycle via Mouser/TME API) and settle replacement types
  for IC2.
- **1S2473** (Si diode), **µA7805**: uncritical, but check as well.
- Data sheets for 2SB596 (MOSPEC) and 2SD880 (DC Components) were read for the pin
  assignment but are not in the repo (copyright).

## Versions

**Rev0.5** (230 V) and **Rev0.5-110V** change no tracks and no parts positions: all board corners
are rounded to R5 (house rule; DRC unchanged: 0 errors, 0 unconnected, parity 0 for both), a
voltage mark is added to the silkscreen (Rev0.5 moves it clear of the fuse holder outline), and the 110 V variant takes the 100/117 V parts of the
original (fuses 0.5 A, transformer N-218C, switch SDG5P-001). The mains clearance and creepage
figures above apply to both, since the copper is identical; the lower voltage only relaxes the
requirement and is not separately assessed. The 110 V transformer is a 117 V part, 110 V is 6 %
below its rating (not measured).

**Rev0.3** replaces the solder lugs of the 230 V primary side (terminals 1–9: mains lead,
mains switch, transformer input) with four RM5.0 screw terminals (X1 poles 1–2, X2 poles 3–4,
X3 poles 5–6, X4 poles 7–9). The pad spacing of adjacent poles is set by the pitch: 2.4 mm
edge to edge (L and N sit next to each other in X3 and X4). The terminals are built for mains
voltage; whether the board meets today's creepage distances there depends, as with any
terminal block, on the terminal manufacturer and is not demonstrated here. Tracks between the
mains conductors: at least 4.0 mm.

**Rev0.1** is the historical 1:1 copy (release `Rev0.1`). **Rev0.2** changes only the mains
side: SW_B is moved away from SW_A and from pad F1.1 (SW_A/SW_B at least 5.67 mm). Every
layout change is a new version: files renamed, version on the silkscreen, own release.

## Next step (gate before manufacturing)

Have a sample made, compare dimensions against the real board (validation 1) and only then
larger quantities. A gate is not passed "provisionally". Whoever passes the board on or sells
it is responsible for safety and CE marking.

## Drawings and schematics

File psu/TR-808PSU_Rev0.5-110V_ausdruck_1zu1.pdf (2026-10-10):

## TR-808PSU_Rev0.5-110V - Bestückungsseite (Ansicht von oben)

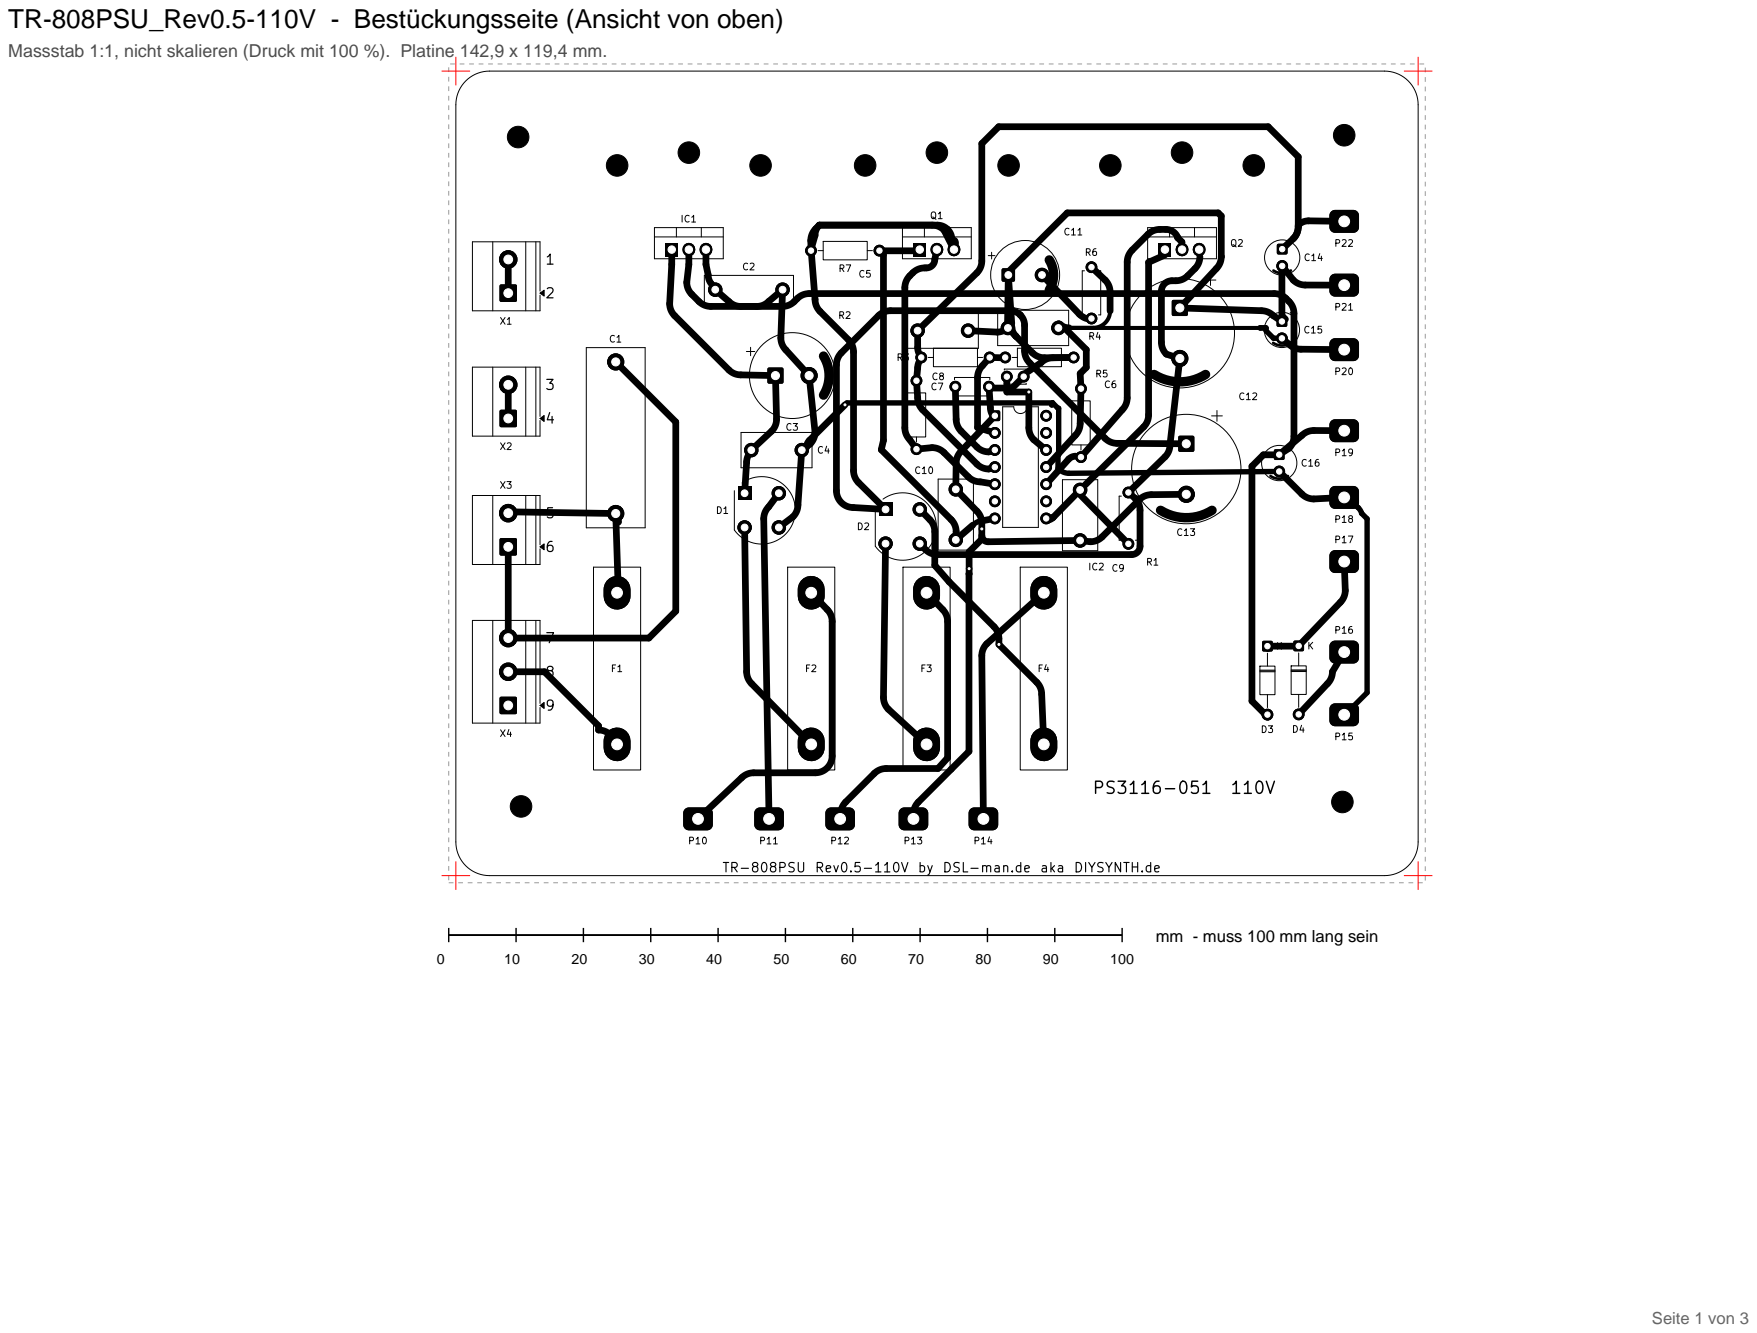
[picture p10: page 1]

Massstab 1:1, nicht skalieren (Druck mit 100 %). Platine 142,9 x 119,4 mm.

TR-808PSU Rev0.5-110V by DSL-man.de aka DIYSYNTH.de 2

mm - muss 100 mm lang sein

## TR-808PSU_Rev0.5-110V - Lötseite, Kupfer (Ansicht von oben durch die Platine)

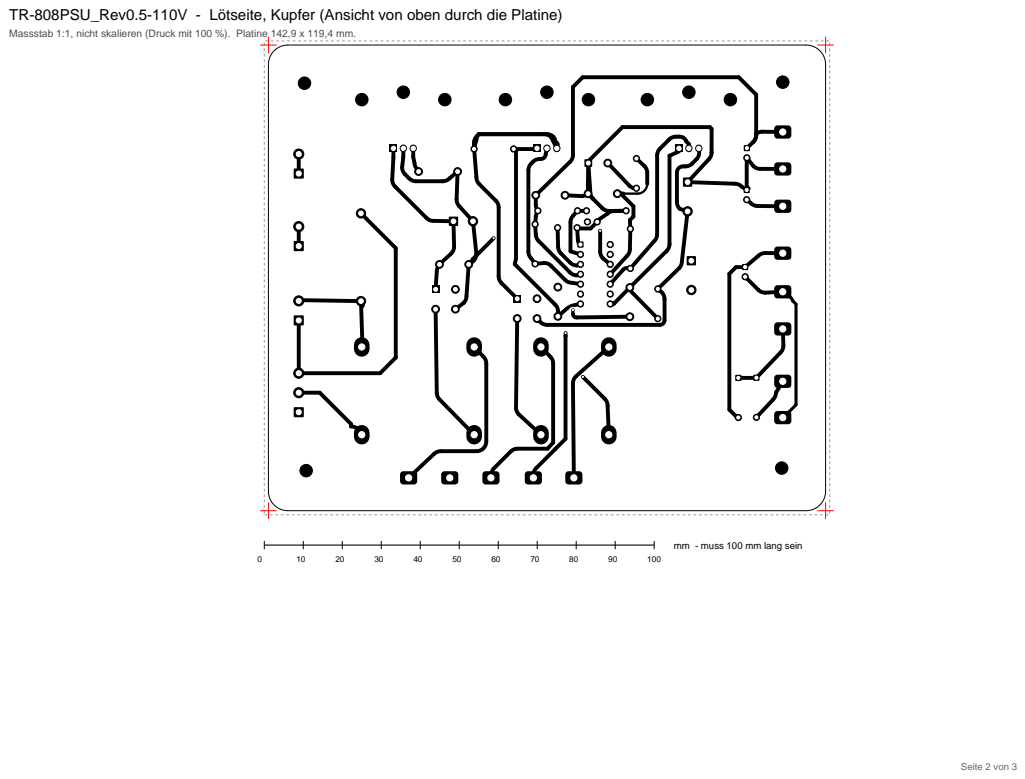
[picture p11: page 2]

mm - muss 100 mm lang sein

## TR-808PSU_Rev0.5-110V - Bohrschablone: Umriss und Bohrungen

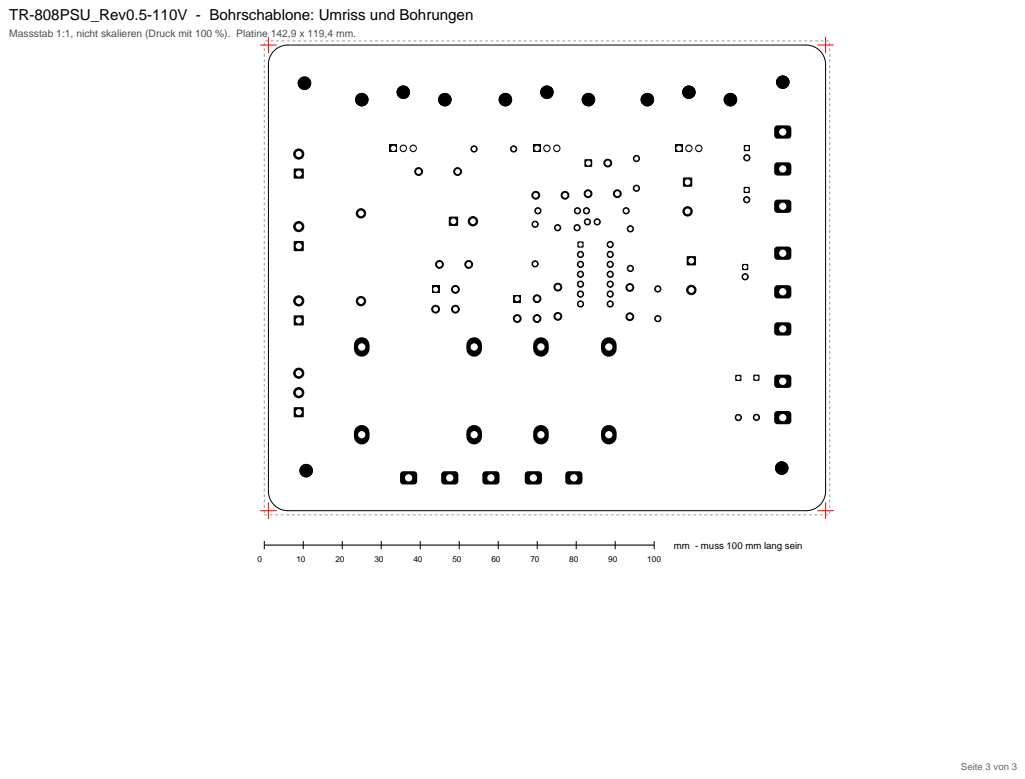
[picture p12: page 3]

mm - muss 100 mm lang sein

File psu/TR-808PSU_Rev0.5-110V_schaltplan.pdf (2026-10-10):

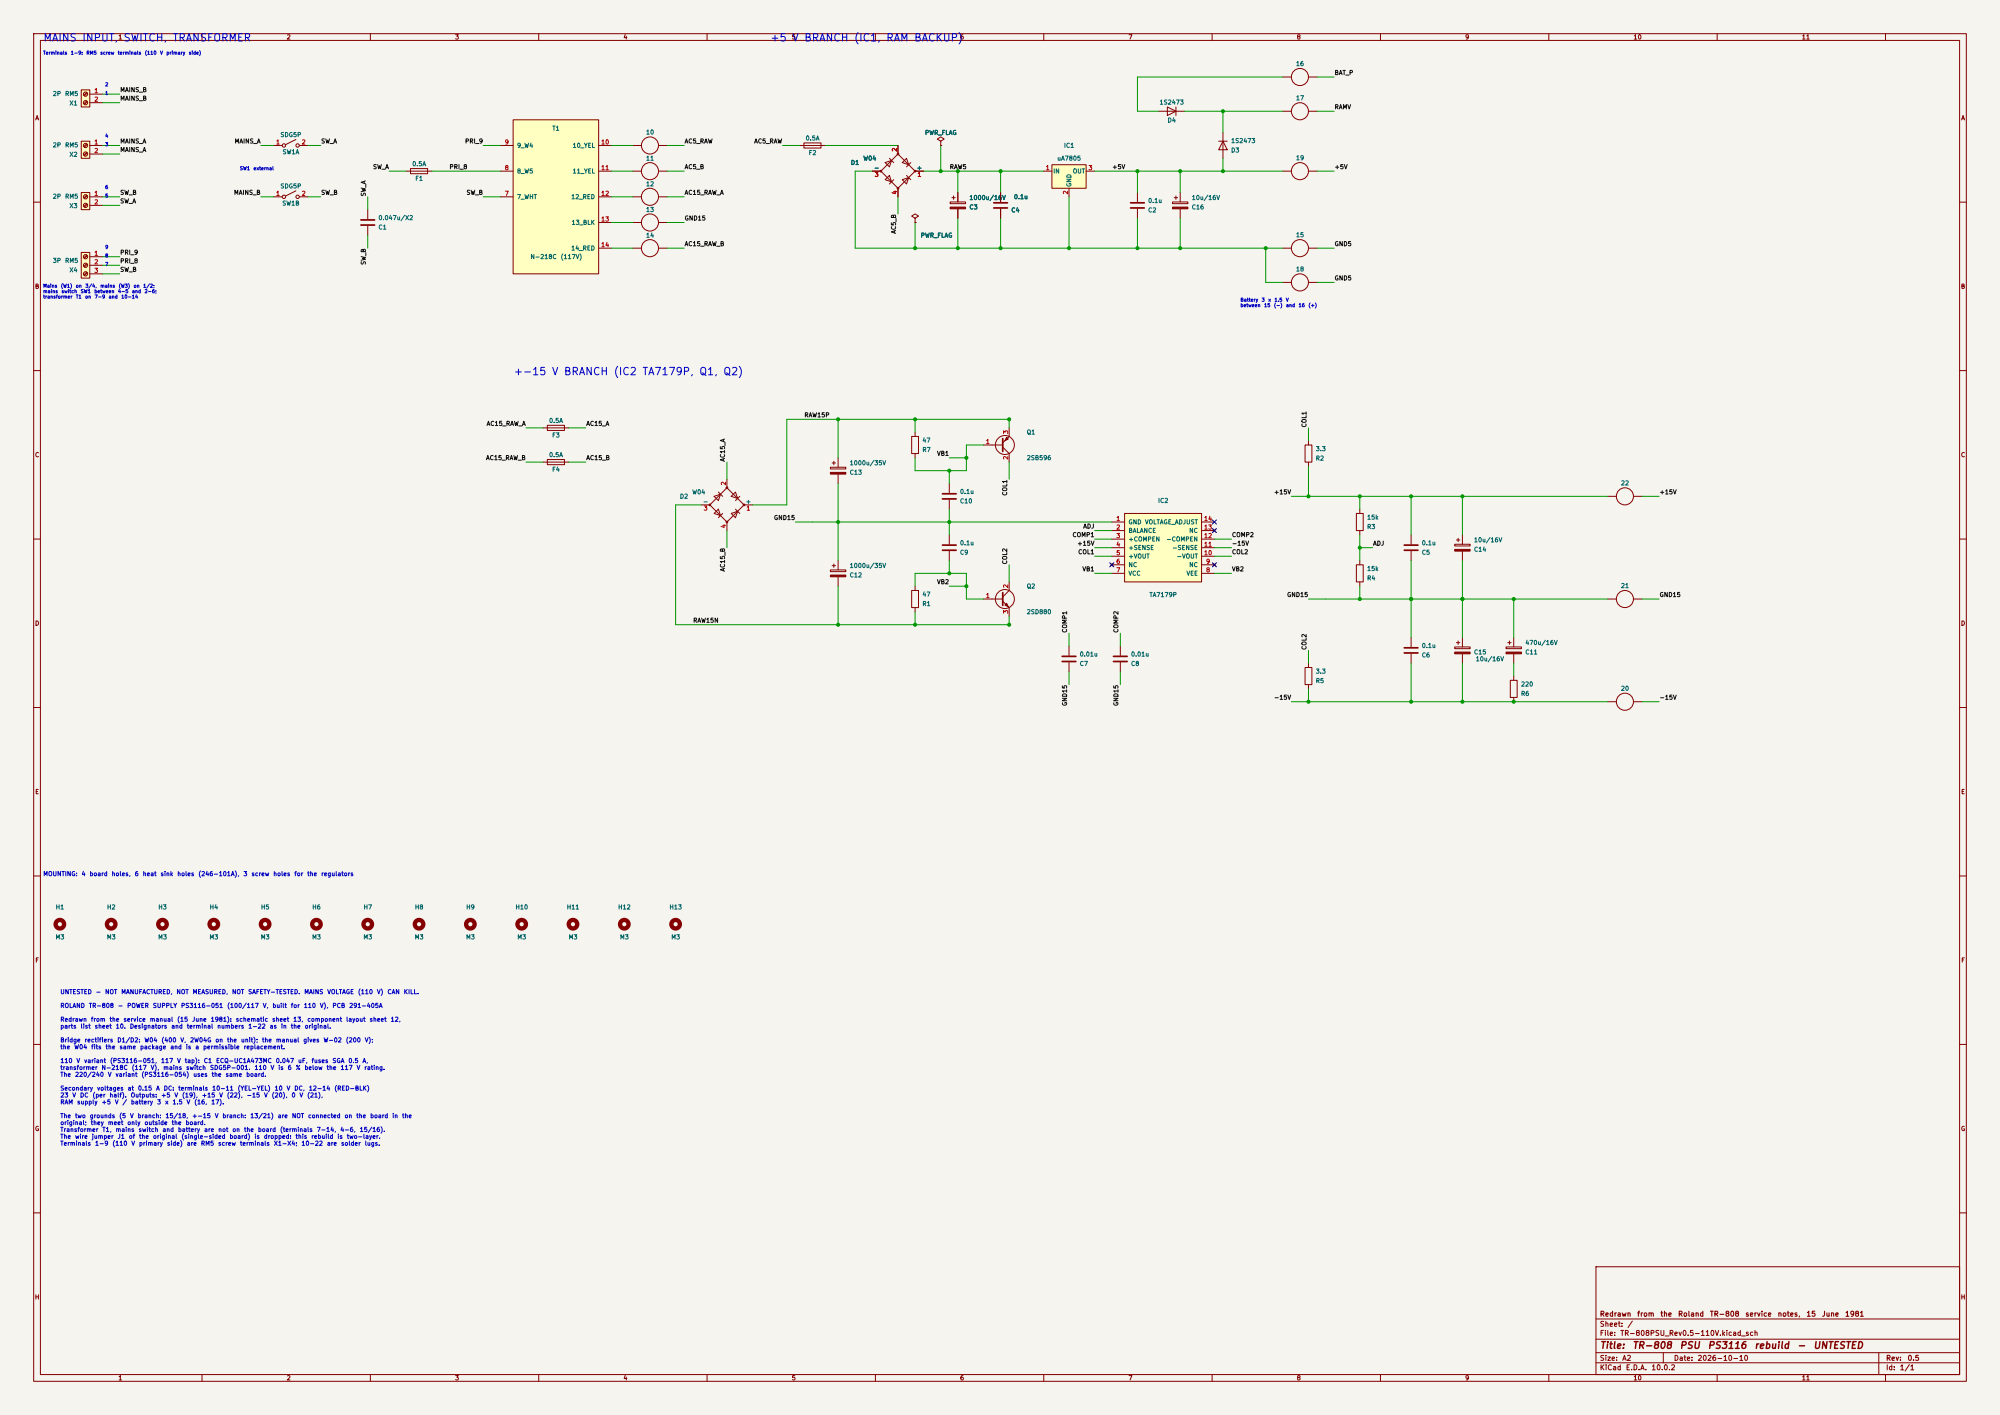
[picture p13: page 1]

SW1 external 4 MAINS INPUT, SWITCH, TRANSFORMER

Terminals 1-9: RM5 screw terminals (110 V primary side) 1

Bridge rectifiers D1/D2: W04 (400 V, 2W04G on the unit); the manual gives W-02 (200 V); the W04 fits the same package and is a permissible replacement. 110 V variant (PS3116-051, 117 V tap): C1 ECQ-UC1A473MC 0.047 uF, fuses SGA 0.5 A, transformer N-218C (117 V), mains switch SDG5P-001. 110 V is 6 % below the 117 V rating. The 220/240 V variant (PS3116-054) uses the same board. Secondary voltages at 0.15 A DC: terminals 10-11 (YEL-YEL) 10 V DC, 12-14 (RED-BLK) 23 V DC (per half). Outputs: +5 V (19), +15 V (22), -15 V (20), 0 V (21), RAM supply +5 V / battery 3 x 1.5 V (16, 17). The two grounds (5 V branch: 15/18, +-15 V branch: 13/21) are NOT connected on the board in the original; they meet only outside the board. Transformer T1, mains switch and battery are not on the board (terminals 7-14, 4-6, 15/16). The wire jumper J1 of the original (single-sided board) is dropped: this rebuild is two-layer. Terminals 1-9 (110 V primary side) are RM5 screw terminals X1-X4; 10-22 are solder lugs. MOUNTING: 4 board holes, 6 heat sink holes (246-101A), 3 screw holes for the regulators

UNTESTED - NOT MANUFACTURED, NOT MEASURED, NOT SAFETY-TESTED. MAINS VOLTAGE (110 V) CAN KILL. ROLAND TR-808 - POWER SUPPLY PS3116-051 (100/117 V, built for 110 V), PCB 291-405A Redrawn from the service manual (15 June 1981): schematic sheet 13, component layout sheet 12,

parts list sheet 10. Designators and terminal numbers 1-22 as in the original.

Redrawn from the Roland TR-808 service notes, 15 June 1981
Sheet: /
File: TR-808PSU_Rev0.5-110V.kicad_sch
Title: TR-808 PSU PS3116 rebuild - UNTESTED

Size: A2 | Rev: 0.5
KiCad E.D.A. 10.0.2 | Id: 1/1

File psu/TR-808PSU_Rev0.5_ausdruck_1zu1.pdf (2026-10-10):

## TR-808PSU_Rev0.5 - Bestückungsseite (Ansicht von oben)

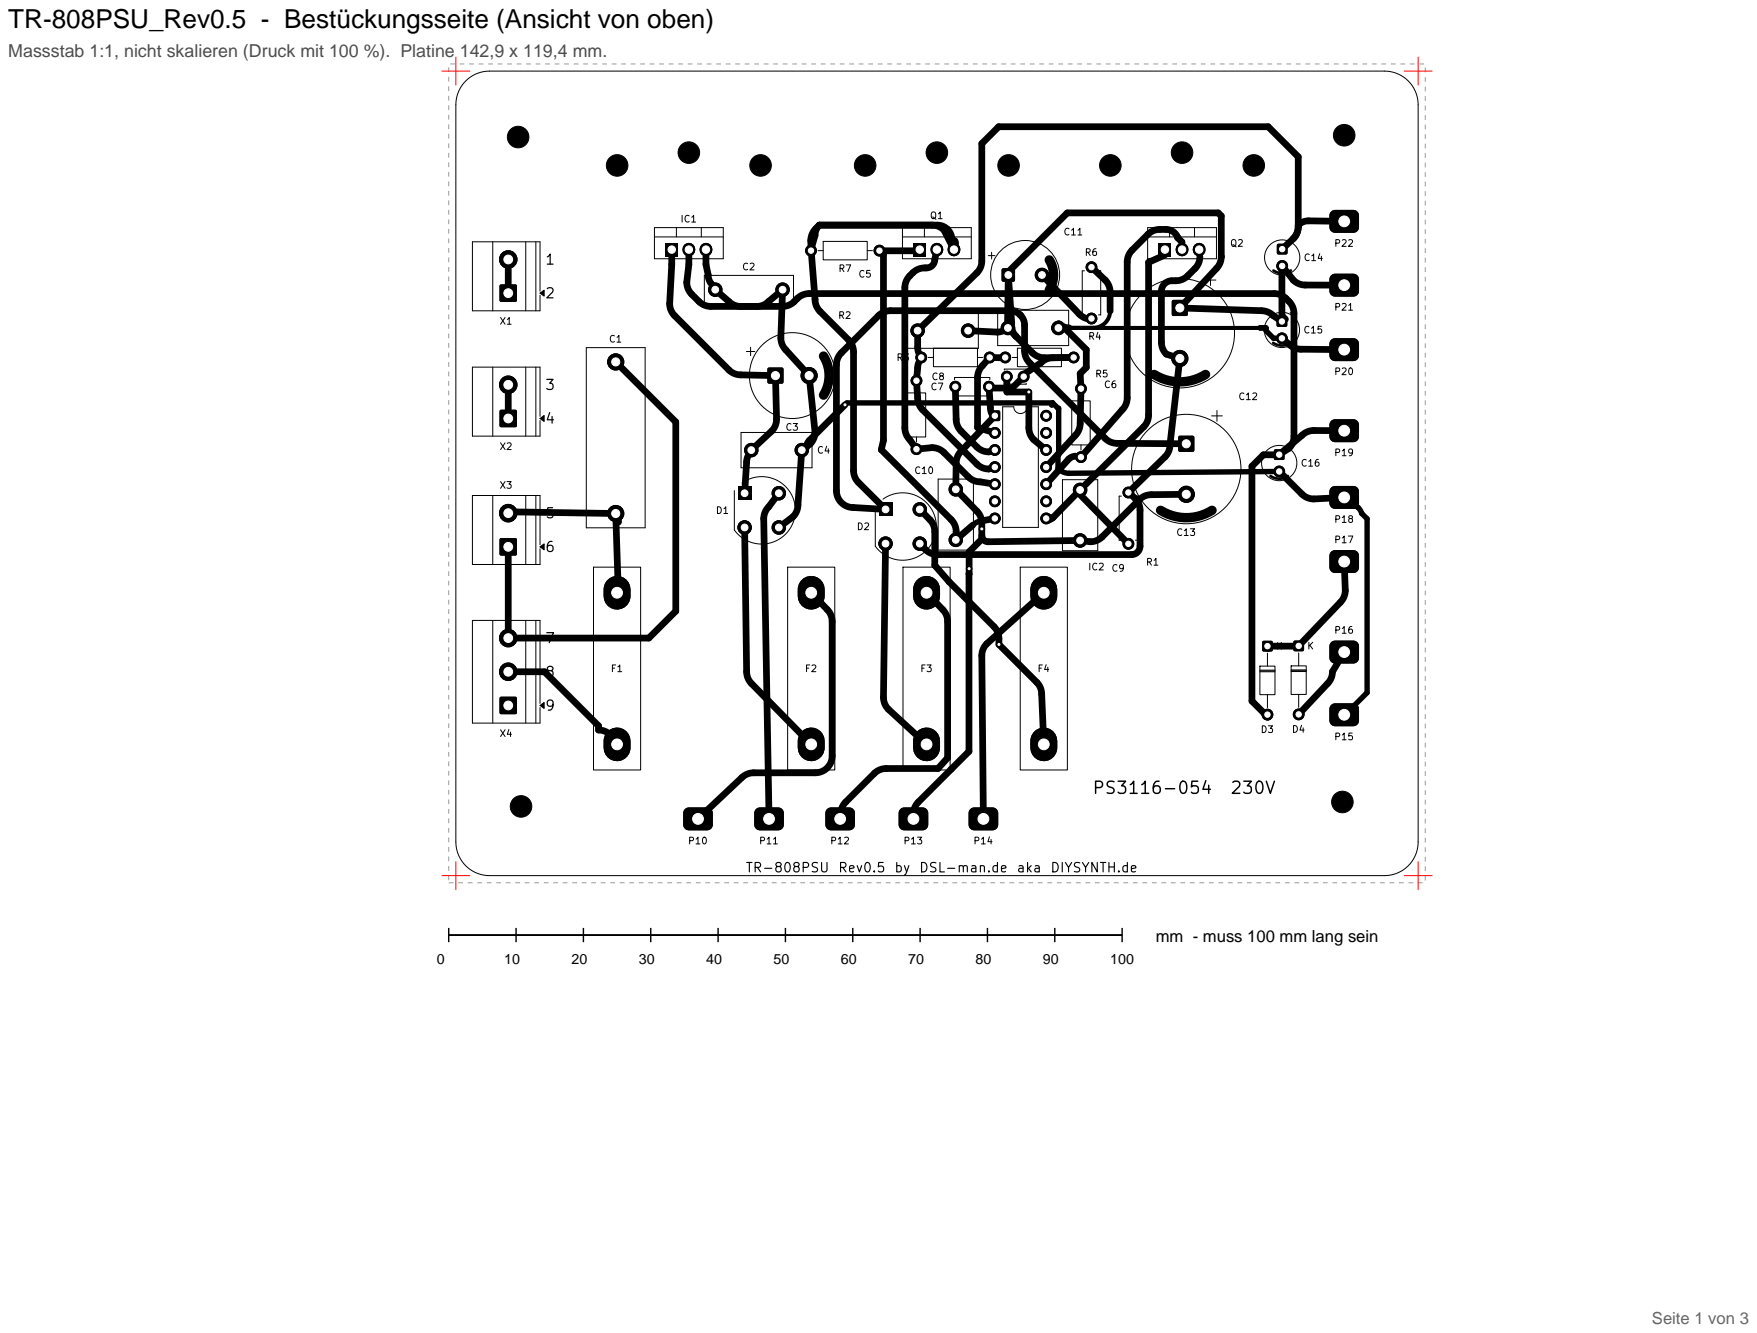
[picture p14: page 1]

Massstab 1:1, nicht skalieren (Druck mit 100 %). Platine 142,9 x 119,4 mm.

TR-808PSU Rev0.5 by DSL-man.de aka DIYSYNTH.de 2

mm - muss 100 mm lang sein

## TR-808PSU_Rev0.5 - Lötseite, Kupfer (Ansicht von oben durch die Platine)

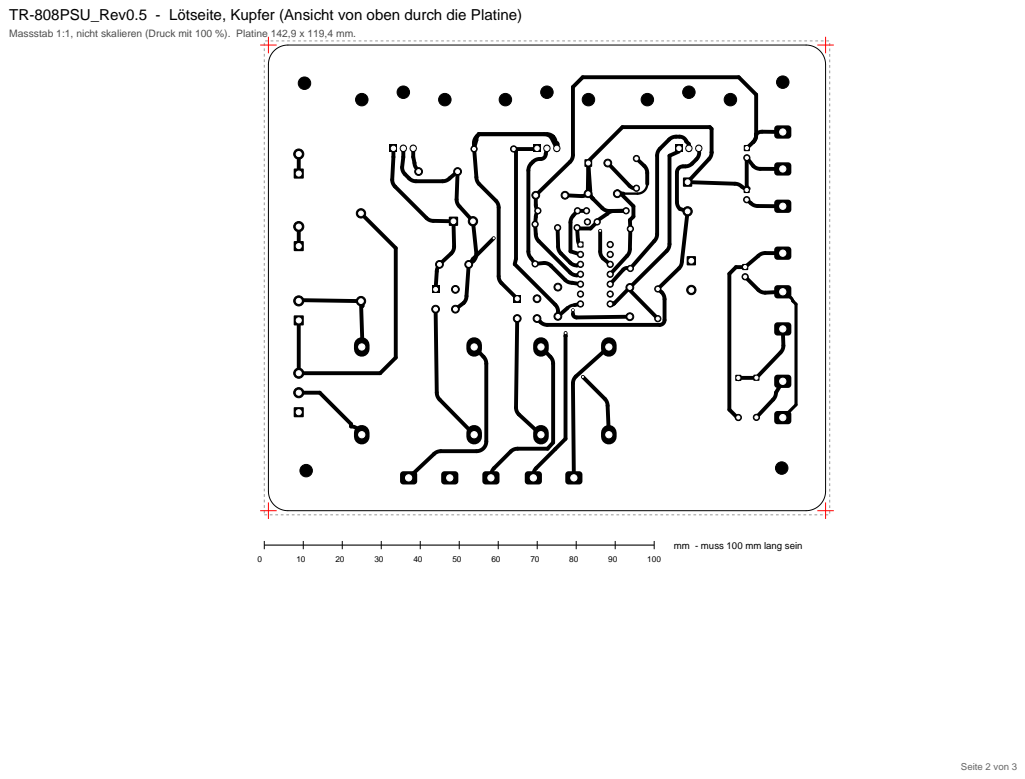
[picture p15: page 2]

mm - muss 100 mm lang sein

## TR-808PSU_Rev0.5 - Bohrschablone: Umriss und Bohrungen

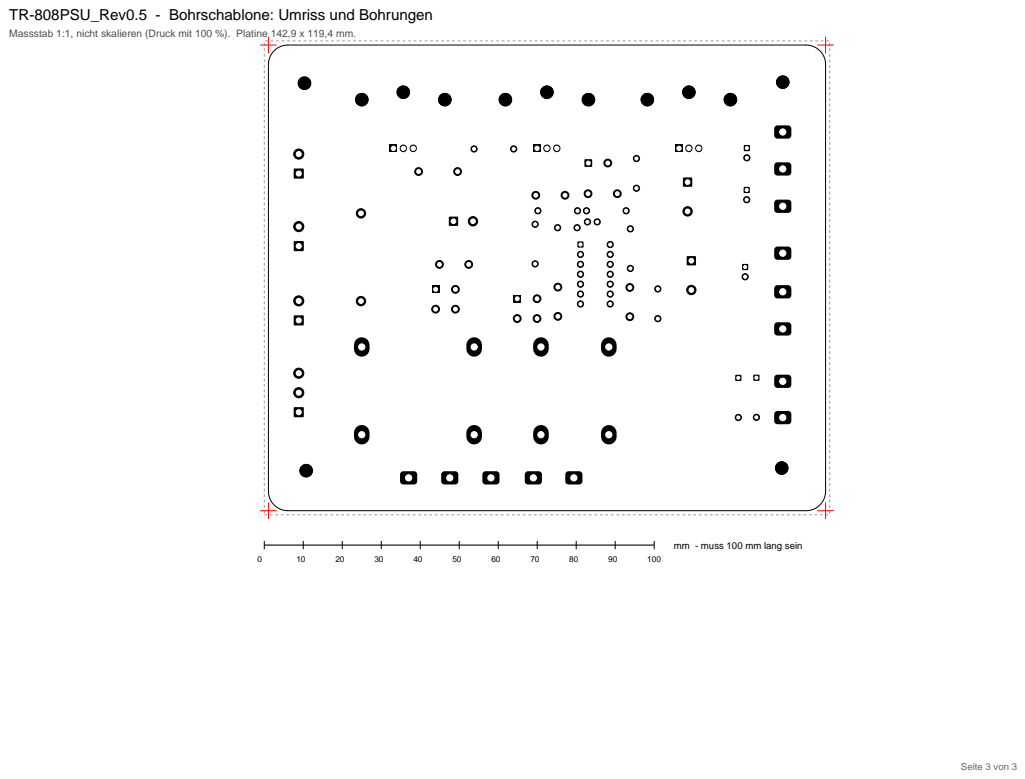
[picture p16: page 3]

mm - muss 100 mm lang sein

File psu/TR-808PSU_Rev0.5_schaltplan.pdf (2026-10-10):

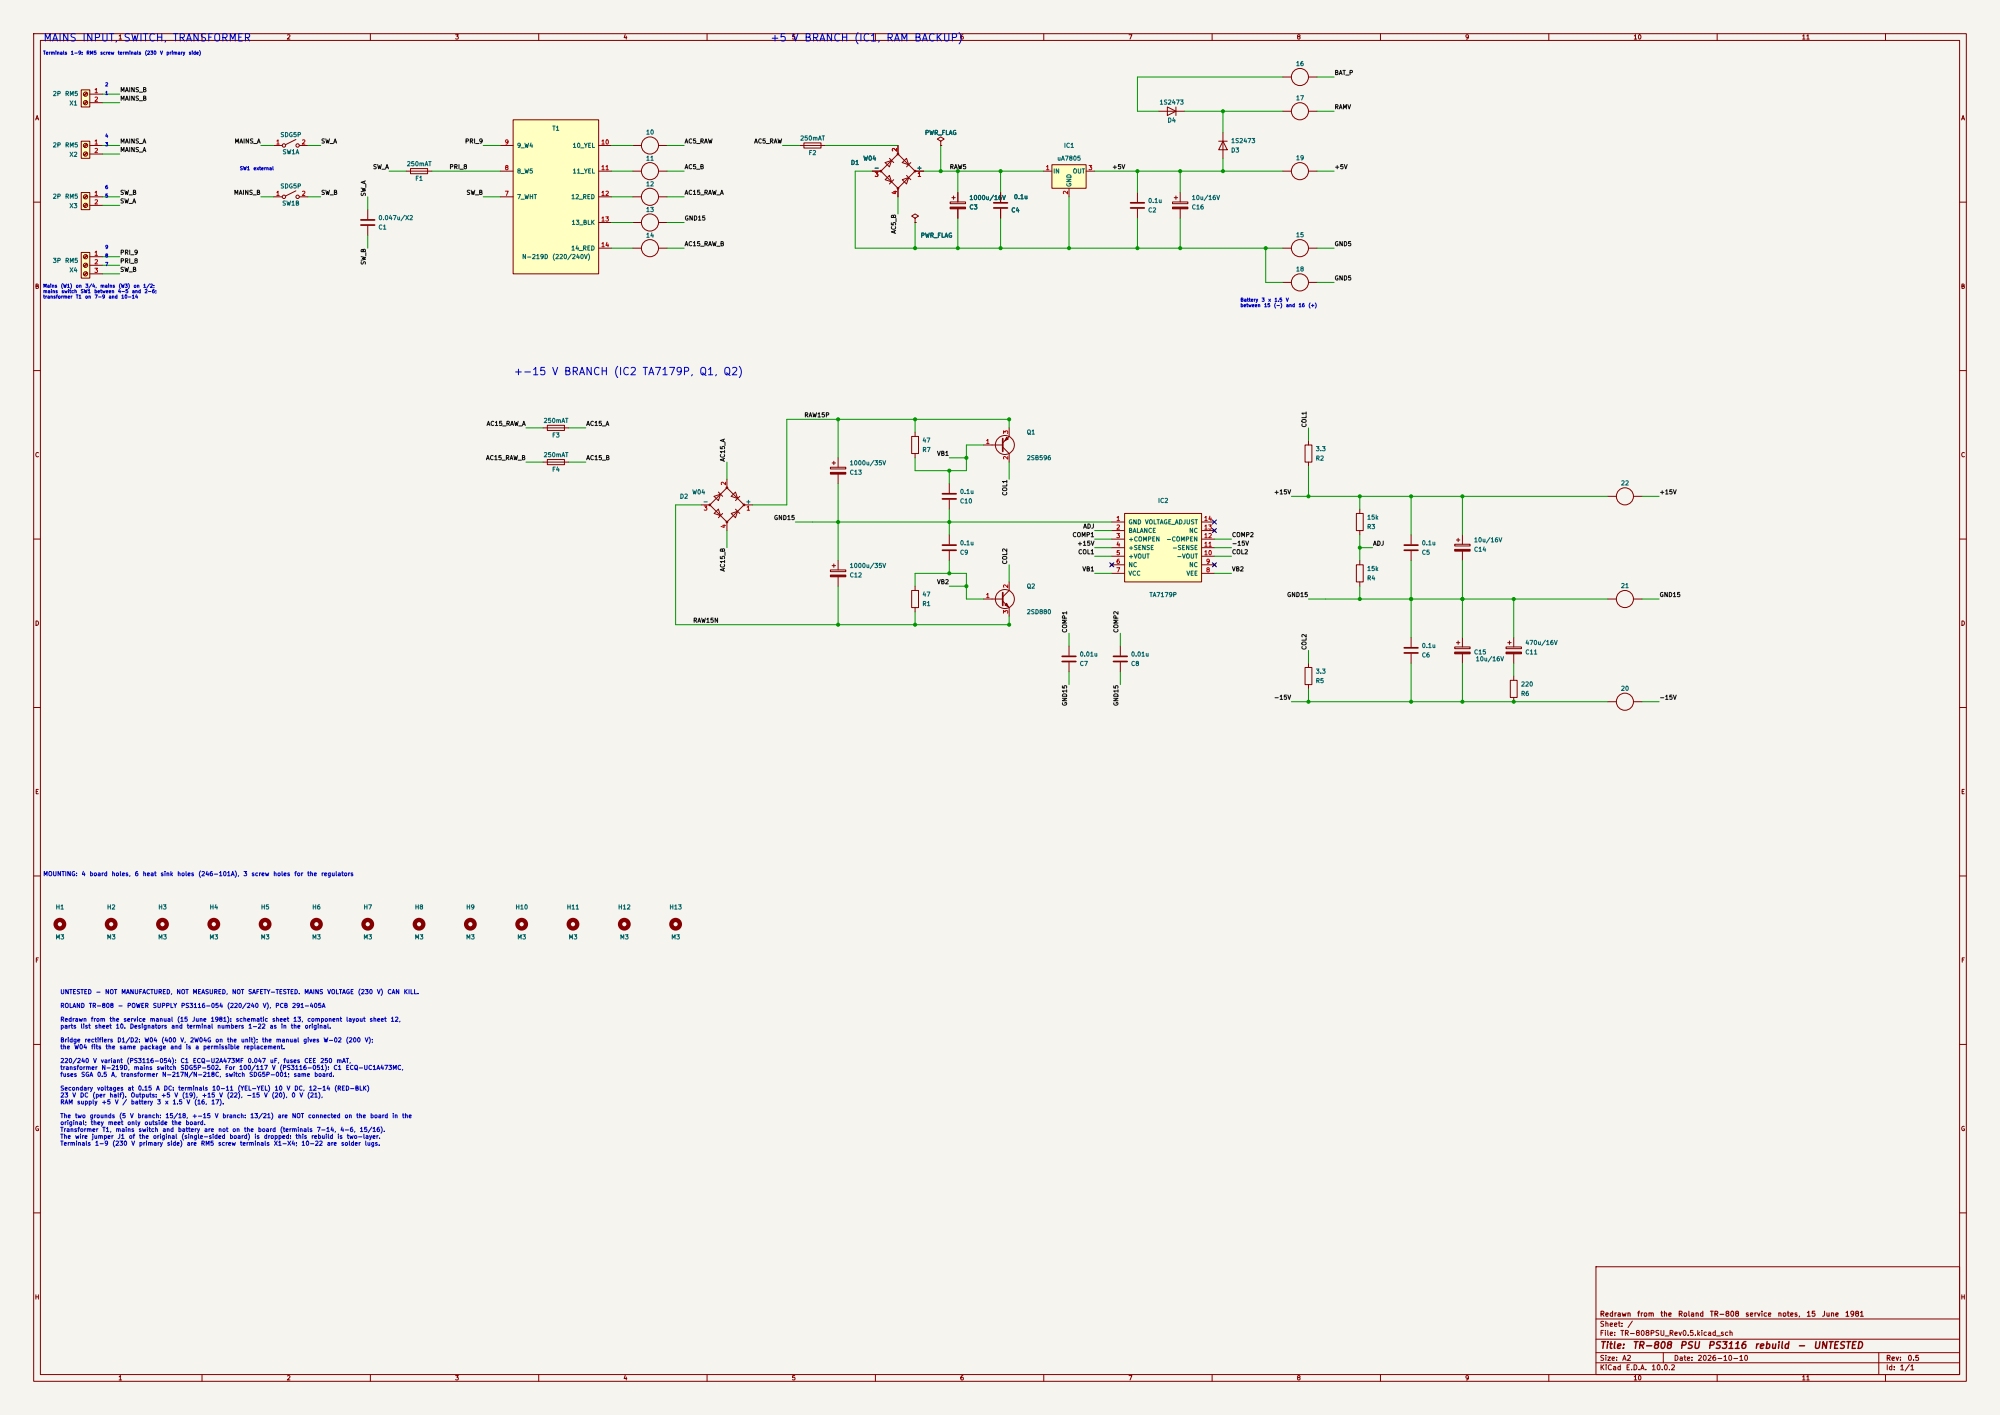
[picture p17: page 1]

SW1 external 4 MAINS INPUT, SWITCH, TRANSFORMER

Terminals 1-9: RM5 screw terminals (230 V primary side) 1

Redrawn from the Roland TR-808 service notes, 15 June 1981
Sheet: /
File: TR-808PSU_Rev0.5.kicad_sch
Title: TR-808 PSU PS3116 rebuild - UNTESTED

Size: A2 | Rev: 0.5
KiCad E.D.A. 10.0.2 | Id: 1/1

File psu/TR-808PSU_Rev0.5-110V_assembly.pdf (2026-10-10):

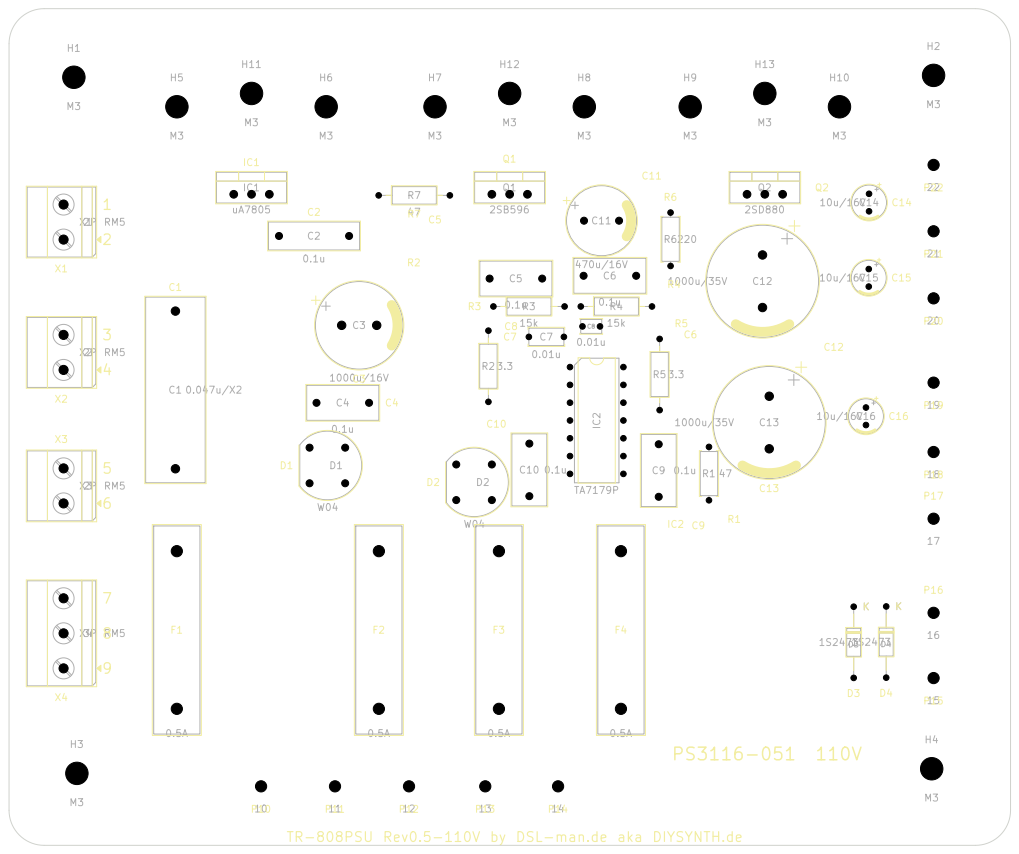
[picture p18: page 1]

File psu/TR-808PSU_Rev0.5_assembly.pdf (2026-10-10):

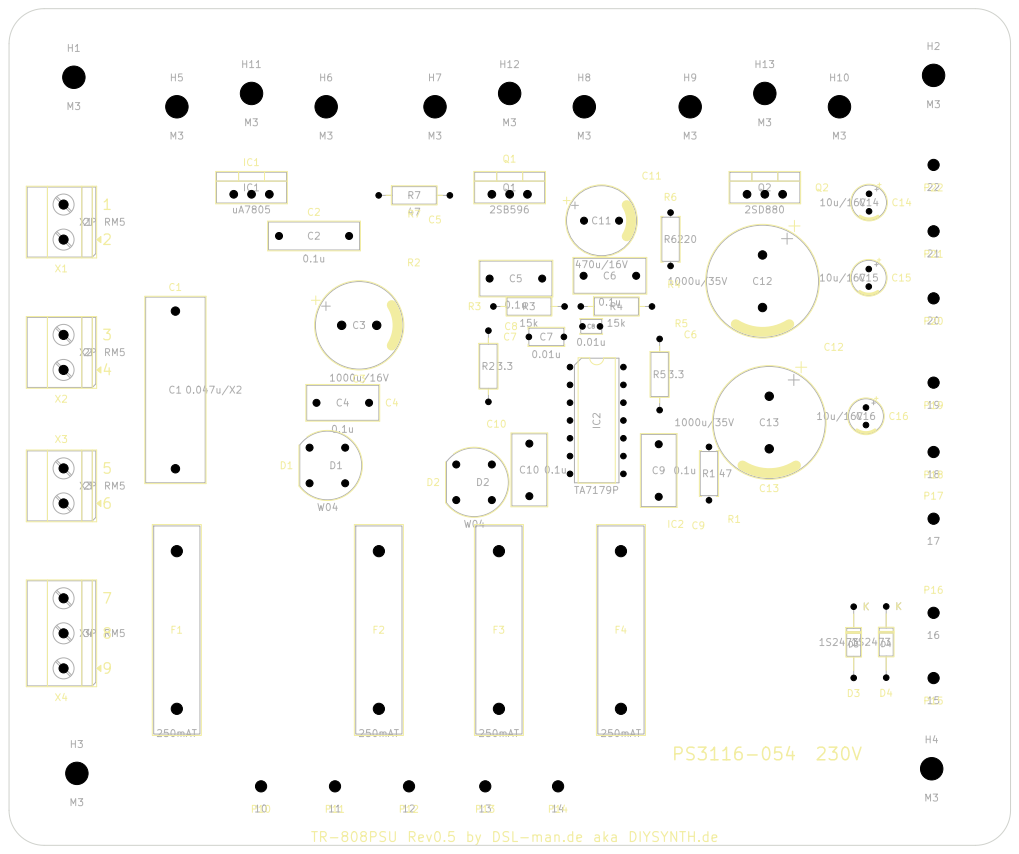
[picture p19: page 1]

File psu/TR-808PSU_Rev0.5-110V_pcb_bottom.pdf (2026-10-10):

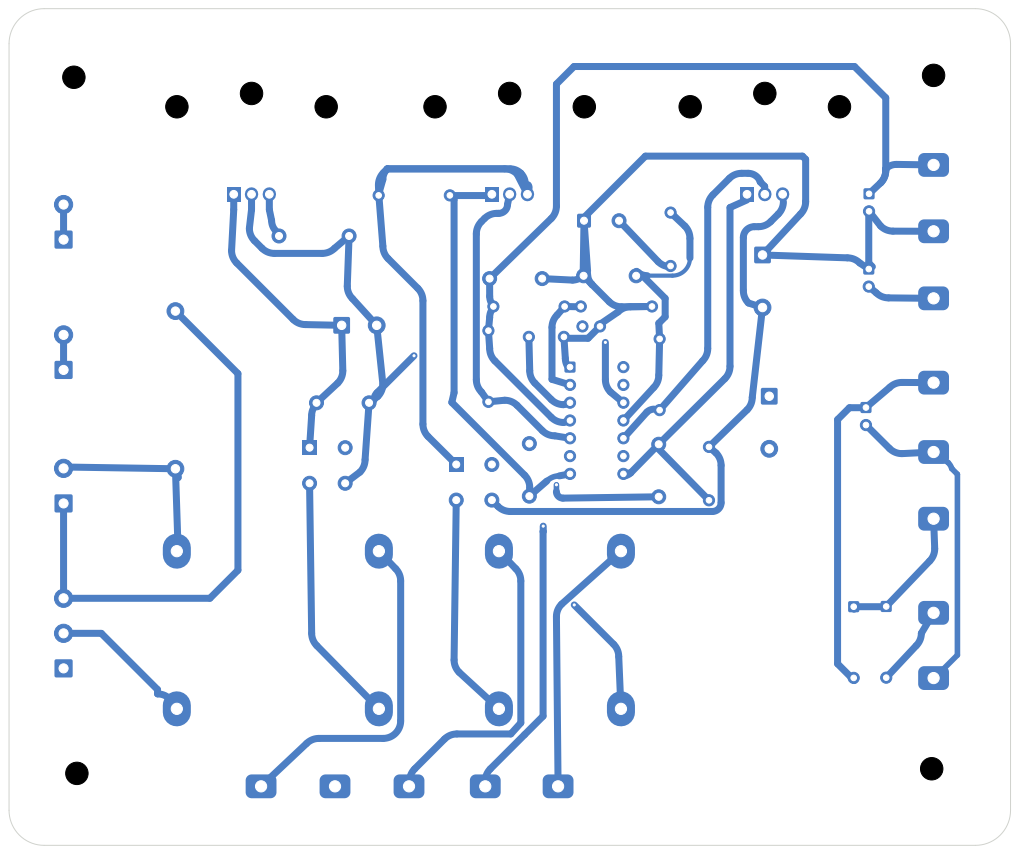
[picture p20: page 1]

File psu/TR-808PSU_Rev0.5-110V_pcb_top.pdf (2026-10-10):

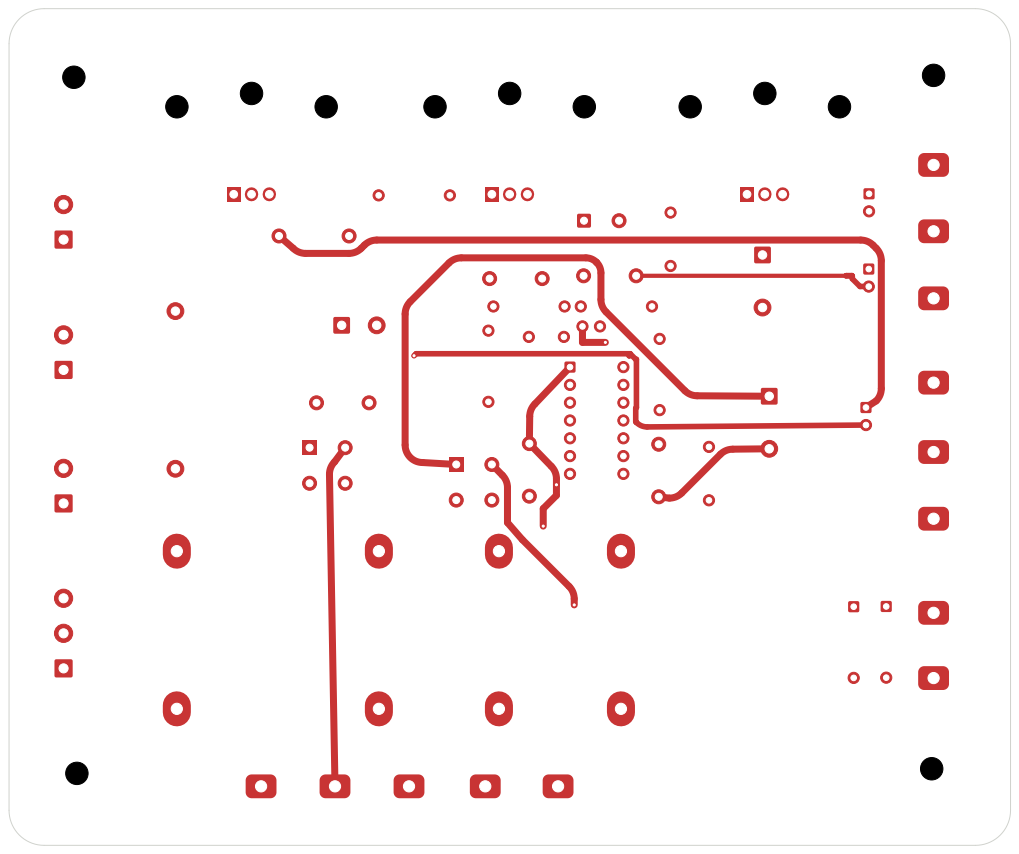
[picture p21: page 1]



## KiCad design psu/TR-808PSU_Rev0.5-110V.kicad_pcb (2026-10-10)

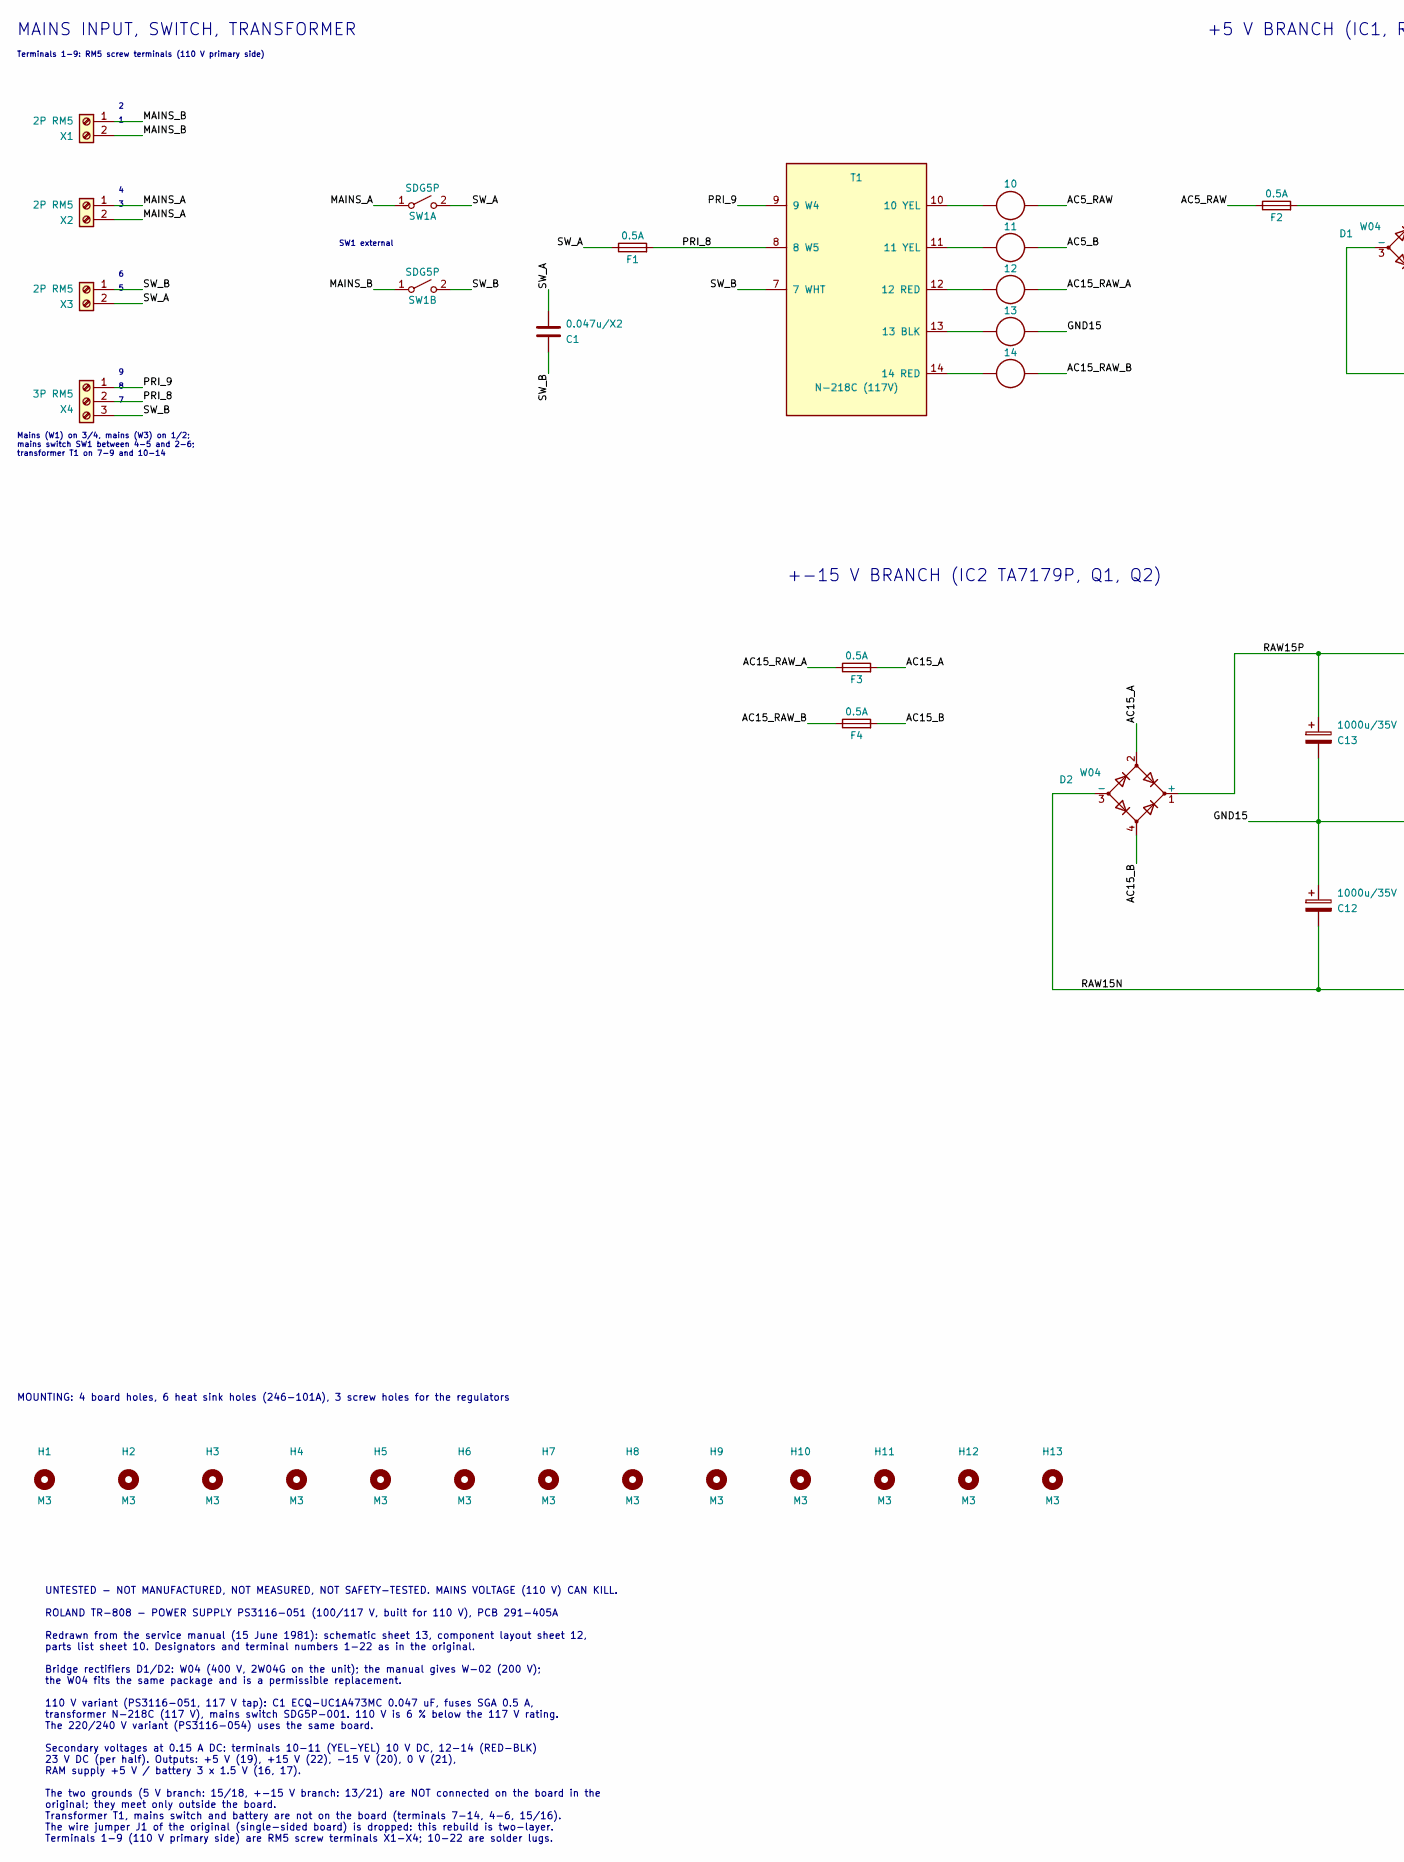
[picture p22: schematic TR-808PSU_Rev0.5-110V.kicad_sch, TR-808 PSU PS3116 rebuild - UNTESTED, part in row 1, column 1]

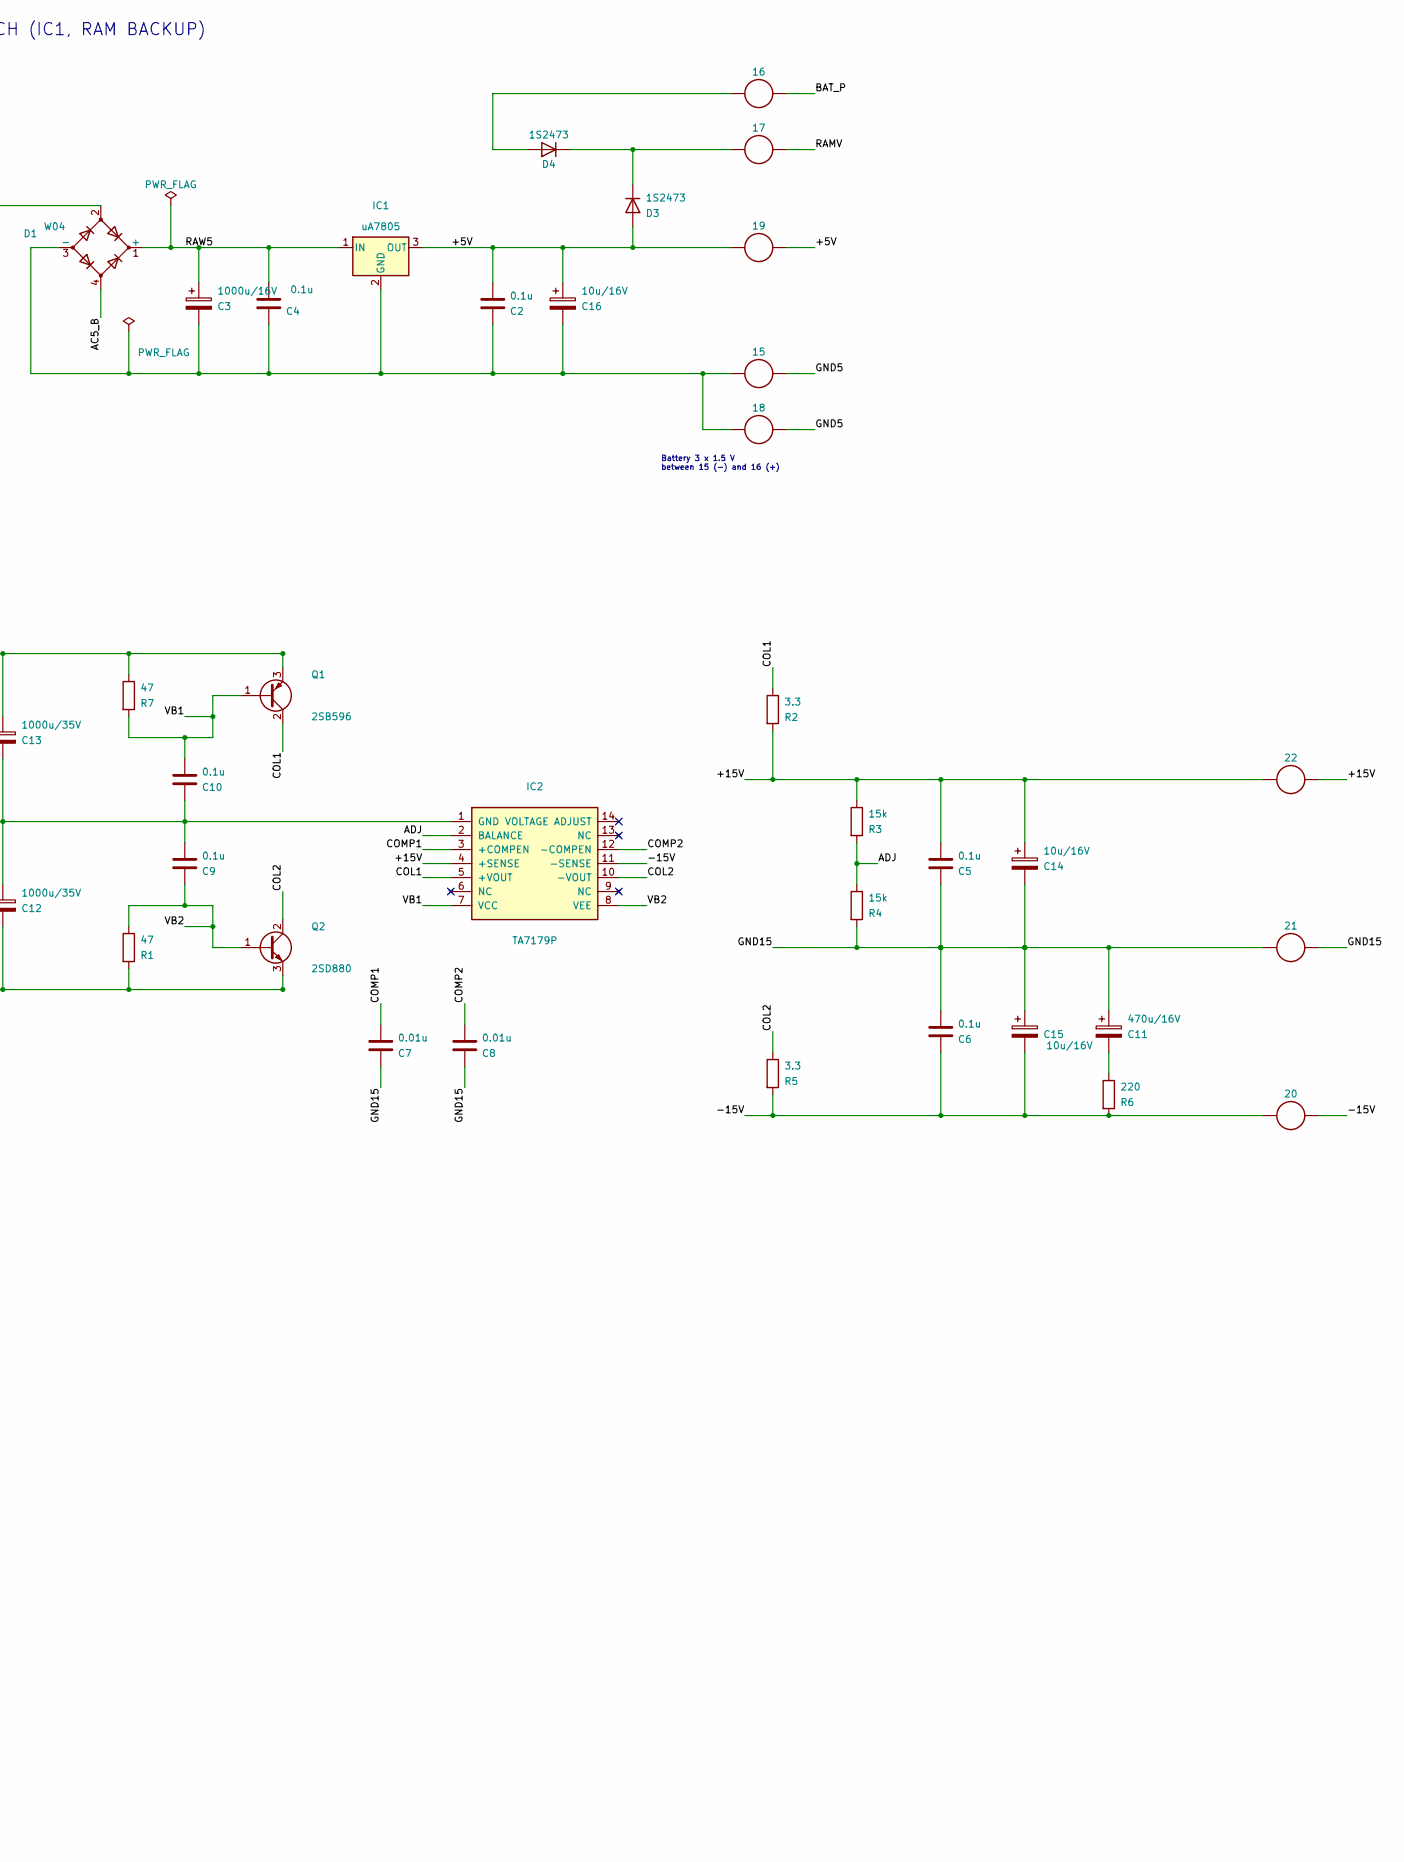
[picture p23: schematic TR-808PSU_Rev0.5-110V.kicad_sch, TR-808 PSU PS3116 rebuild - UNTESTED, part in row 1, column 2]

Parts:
C1: 0.047u/X2; C_Rect_L26.5mm_W8.5mm_P22.50mm_MKS4
C2: 0.1u; C_Rect_L13.0mm_W4.0mm_P10.00mm_FKS3_FKP3_MKS4
C3: 1000u/16V; CP_Radial_D12.5mm_P5.00mm
C4, C5, C6, C9, C10: 0.1u; C_Rect_L10.3mm_W5.0mm_P7.50mm_MKS4
C7: 0.01u; C_Disc_D5.0mm_W2.5mm_P5.00mm
C8: 0.01u; C_Disc_D3.0mm_W2.0mm_P2.50mm
C11: 470u/16V; CP_Radial_D10.0mm_P5.00mm
C12, C13: 1000u/35V; CP_Radial_D16.0mm_P7.50mm
C14, C15, C16: 10u/16V; CP_Radial_D5.0mm_P2.50mm
D1, D2: W04; Diode_Bridge_Round_D9.8mm
D3, D4: 1S2473; D_DO-35_SOD27_P10.16mm_Horizontal
F1, F2, F3, F4: 0.5A; FuseClip_5x20_TF785
H1, H2, H3, H4, H5, H6, H7, H8, H9, H10, H11, H12, H13: M3; MountingHole_3.2mm_M3
IC1: uA7805; TO-220-3_Vertical
IC2: TA7179P; DIP-14_W7.62mm
P10: 10; Terminal_Pin
P11: 11; Terminal_Pin
P12: 12; Terminal_Pin
P13: 13; Terminal_Pin
P14: 14; Terminal_Pin
P15: 15; Terminal_Pin
P16: 16; Terminal_Pin
P17: 17; Terminal_Pin
P18: 18; Terminal_Pin
P19: 19; Terminal_Pin
P20: 20; Terminal_Pin
P21: 21; Terminal_Pin
P22: 22; Terminal_Pin
Q1: 2SB596; TO-220-3_Vertical
Q2: 2SD880; TO-220-3_Vertical
R1: 47; R_Axial_DIN0207_L6.3mm_D2.5mm_P7.62mm_Horizontal
R2, R5: 3.3; R_Axial_DIN0207_L6.3mm_D2.5mm_P10.16mm_Horizontal
R3, R4: 15k; R_Axial_DIN0207_L6.3mm_D2.5mm_P10.16mm_Horizontal
R6: 220; R_Axial_DIN0207_L6.3mm_D2.5mm_P7.62mm_Horizontal
R7: 47; R_Axial_DIN0207_L6.3mm_D2.5mm_P10.16mm_Horizontal
SW1A, SW1B: SDG5P
T1: N-218C (117V)
X1, X2, X3: 2P RM5; TerminalBlock_Phoenix_MKDS-1,5-2_1x02_P5.00mm_Horizontal
X4: 3P RM5; TerminalBlock_Phoenix_MKDS-1,5-3_1x03_P5.00mm_Horizontal

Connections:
/+5V: C2.1, C16.1, D3.2 (A), IC1.3 (OUT), P19.1
/+15V: C5.1, C14.1, IC2.4 (+SENSE), P22.1, R2.2, R3.1
/-15V: C6.2, C15.2, IC2.11 (-SENSE), P20.1, R5.2, R6.2
/AC5_B: D1.4, P11.1, T1.11 (11 YEL)
/AC5_RAW: F2.1, P10.1, T1.10 (10 YEL)
/AC15_A: D2.2, F3.2
/AC15_B: D2.4, F4.2
/AC15_RAW_A: F3.1, P12.1, T1.12 (12 RED)
/AC15_RAW_B: F4.1, P14.1, T1.14 (14 RED)
/ADJ: IC2.2 (BALANCE), R3.2, R4.1
/BAT_P: D4.2 (A), P16.1
/COL1: IC2.5 (+VOUT), Q1.2 (C), R2.1
/COL2: IC2.10 (-VOUT), Q2.2 (C), R5.1
/COMP1: C7.1, IC2.3 (+COMPEN)
/COMP2: C8.1, IC2.12 (-COMPEN)
/GND5: C2.2, C3.2, C4.2, C16.2, D1.3 (-), IC1.2 (GND), P15.1, P18.1
/GND15: C5.2, C6.1, C7.2, C8.2, C9.1, C10.2, C11.1, C12.1, C13.2, C14.2, C15.1, IC2.1 (GND), P13.1, P21.1, R4.2, T1.13 (13 BLK)
/MAINS_A: SW1A.1 (A), X2.1, X2.2
/MAINS_B: SW1B.1 (A), X1.1, X1.2
/PRI_8: F1.2, T1.8 (8 W5), X4.2
/PRI_9: T1.9 (9 W4), X4.1
/RAMV: D3.1 (K), D4.1 (K), P17.1
/RAW5: C3.1, C4.1, D1.1 (+), IC1.1 (IN)
/RAW15N: C12.2, D2.3 (-), Q2.3 (E), R1.2
/RAW15P: C13.1, D2.1 (+), Q1.3 (E), R7.1
/SW_A: C1.1, F1.1, SW1A.2 (B), X3.2
/SW_B: C1.2, SW1B.2 (B), T1.7 (7 WHT), X3.1, X4.3
/VB1: C10.1, IC2.7 (VCC), Q1.1 (B), R7.2
/VB2: C9.2, IC2.8 (VEE), Q2.1 (B), R1.1
unnamed: C11.2, R6.1
unnamed: D1.2, F2.2

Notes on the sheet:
MAINS INPUT, SWITCH, TRANSFORMER
Terminals 1-9: RM5 screw terminals (110 V primary side)
Mains (W1) on 3/4, mains (W3) on 1/2; mains switch SW1 between 4-5 and 2-6; transformer T1 on 7-9 and 10-14
SW1 external
+5 V BRANCH (IC1, RAM BACKUP)
Battery 3 x 1.5 V between 15 (-) and 16 (+)
+-15 V BRANCH (IC2 TA7179P, Q1, Q2)
MOUNTING: 4 board holes, 6 heat sink holes (246-101A), 3 screw holes for the regulators
UNTESTED - NOT MANUFACTURED, NOT MEASURED, NOT SAFETY-TESTED. MAINS VOLTAGE (110 V) CAN KILL. ROLAND TR-808 - POWER SUPPLY PS3116-051 (100/117 V, built for 110 V), PCB 291-405A Redrawn from the service manual (15 June 1981): schematic sheet 13, component layout sheet 12, parts list sheet 10. Design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

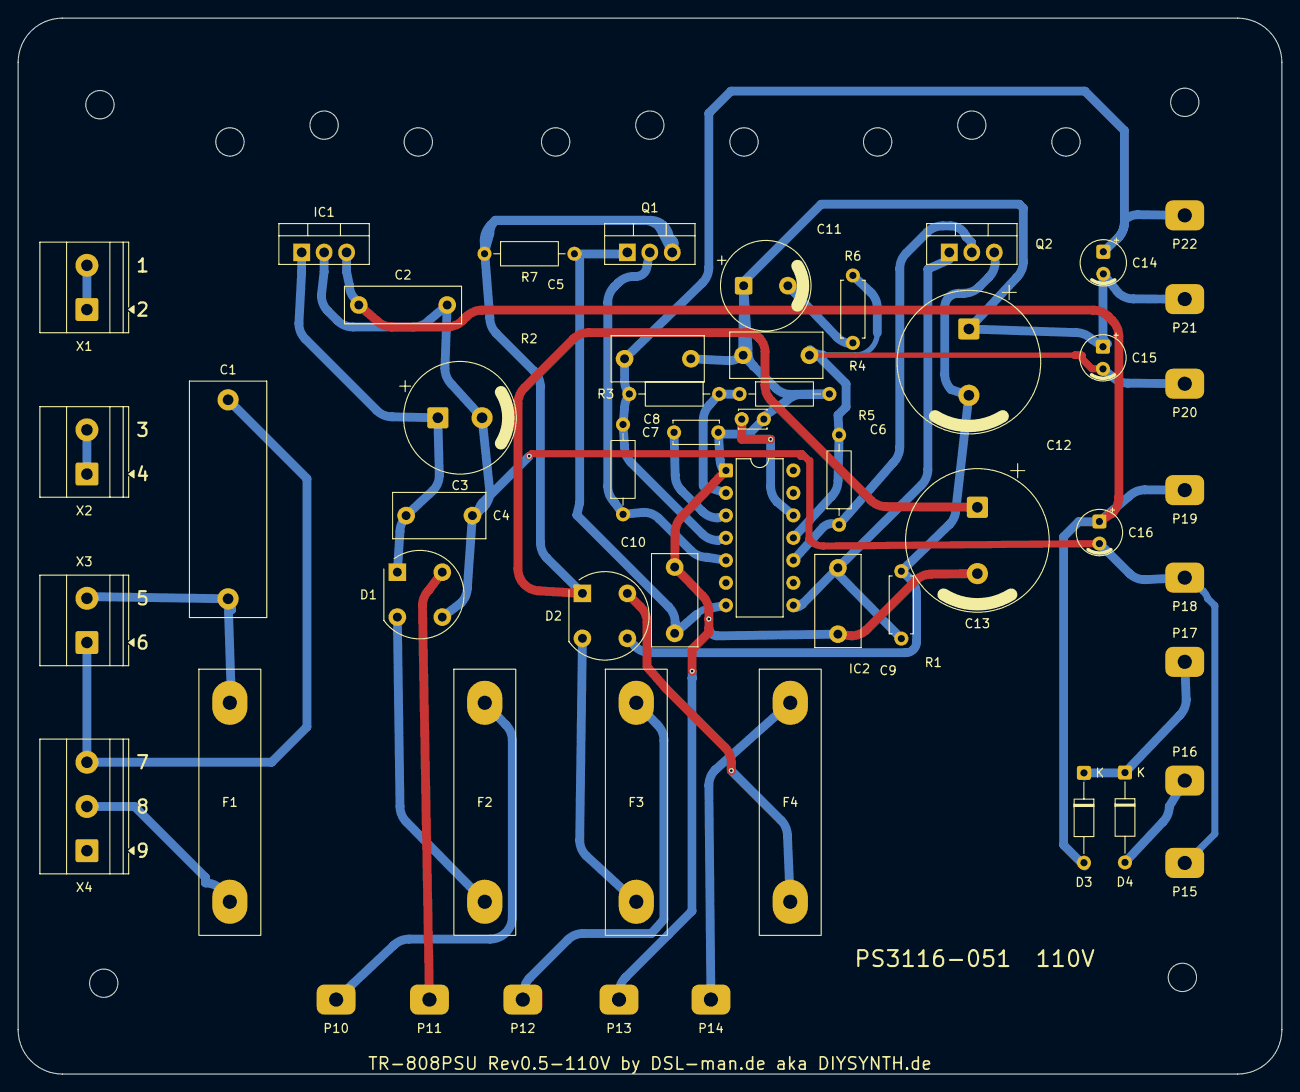
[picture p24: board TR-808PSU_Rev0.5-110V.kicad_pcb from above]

Board: 2 copper layers, 142.9 x 119.4 mm, 65 parts (0 on the bottom side), 30 nets.

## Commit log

2026-10-06 TR-808PSU Rev0.1: Netzteil PS3116 nach Service Manual nachgezeichnet
    Schaltplan wie im Original, Platine mit Positionen aus dem Bestueckungsplan
    (PCB 291-405A), Gerber, Stueckliste, Werkzeugkette.
    [TR-808PSU_Rev0.1-B_Cu.gbr, TR-808PSU_Rev0.1-B_Mask.gbr, TR-808PSU_Rev0.1-B_Silkscreen.gbr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]
2026-10-06 Bahnen am Original-Kupfer geführt: Scan-Abgleich und Leitkarte
    Kupfermaske aus dem Halbtonscan, Bauteile am Kupfer ausgerichtet, Router mit
    Kostenkarte aus den Netzgebieten des Originals. 56 % der Bahnlänge im
    Original-Kupfer, DRC ohne Fehler, keine offenen Verbindungen.
    [TR-808PSU_Rev0.1-B_Cu.gbr, TR-808PSU_Rev0.1-B_Mask.gbr, TR-808PSU_Rev0.1-B_Silkscreen.gbr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]
2026-10-06 Breite Bahnen (1,0 mm) und geglättet mit pcb-glaetten
    Alle Netze breit verlegt (GND5, GND15, COL1 schmal), Via-Kosten hoch, danach
    Treppen zu 45-Grad-Zuegen und Boegen. DRC ohne Fehler, 0 offen, Netzabstand 7,9 mm.
    [TR-808PSU_Rev0.1-B_Cu.gbr, TR-808PSU_Rev0.1-B_Mask.gbr, TR-808PSU_Rev0.1-B_Silkscreen.gbr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]
2026-10-07 Bestueckungsdruck: Bezeichner und Kontur der Sicherungsclips
    Alle Bezeichner (nur diese, keine Werte) auf F.SilkS, frei von Pads, Courtyards und
    voneinander (tools/pcb/silk.py, in make.py eingehaengt); Sicherungsclips mit Siebdruckkontur.
    [TR-808PSU_Rev0.1-B_Cu.gbr, TR-808PSU_Rev0.1-B_Mask.gbr, TR-808PSU_Rev0.1-B_Silkscreen.gbr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]
2026-10-07 Elko-Polaritaetsbalken, Sicherungshalter auf einer Hoehe
    Balken am Minuspol statt Schraffur (polaritaet.py), F1-F4 auf gleicher y-Lage
    (Scan-Abgleich laesst sie fest), Siebdruck-Nacharbeit nach dem KiCad-Speichern.
    DRC 0 Fehler, 0 offen, Netzabstand 6,5 mm.
    [TR-808PSU_Rev0.1-B_Cu.gbr, TR-808PSU_Rev0.1-B_Mask.gbr, TR-808PSU_Rev0.1-B_Silkscreen.gbr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]
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2026-10-07 Alle Bahnen 1,0 mm, Pad-Haarnadeln entfernt, Beschriftung frei von Bahnen
    verbreitern.py (schmale Netze auf 1,0 mm, DRC-geprueft), padstummel.py (Knicke im Pad),
    silk.py meidet Bahnen. DRC 0 Fehler, 0 offen, Netzabstand 6,5 mm.
    [TR-808PSU_Rev0.1-B_Cu.gbr, TR-808PSU_Rev0.1-B_Mask.gbr, TR-808PSU_Rev0.1-B_Silkscreen.gbr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]
2026-10-07 Mehr Abstand: Regel 0,25 mm, Bahnen neu, Nachbessern der Breite
    Abstandsregel von 0,2 auf 0,25 mm (Router, Glaetten, DRC); verbreitern.py bessert Reststellen nach,
    padstummel.py bindet Boegen in der Padrandzone an, silk.py weicht Bahnen aus.
    [TR-808PSU_Rev0.1-B_Cu.gbr, TR-808PSU_Rev0.1-B_Mask.gbr, TR-808PSU_Rev0.1-B_Silkscreen.gbr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]
2026-10-07 Zickzack-Stuecke in den Bahnen gerade gezogen (zickzack.py)
    Folgen aus kurzen Teilen werden durch ein Segment ersetzt, wenn die DRC danach keinen
    neuen Fehler zeigt (9 von 10 Stellen). Beispiel: Treppe unter F3.
    [TR-808PSU_Rev0.1-B_Cu.gbr, TR-808PSU_Rev0.1-B_Mask.gbr, TR-808PSU_Rev0.1-B_Silkscreen.gbr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]
2026-10-07 GND15 neben F3 verlegt: 2,2 mm Abstand statt 0,27 mm
    korrekturen.py (DRC-geprueft, in make.py eingehaengt).
    [TR-808PSU_Rev0.1-B_Cu.gbr, TR-808PSU_Rev0.1-B_Mask.gbr, TR-808PSU_Rev0.1-B_Silkscreen.gbr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]
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2026-10-07 Handanpassung uebernommen, C8 und loses Bahnende korrigiert
    Von Hand: Q2/R7/D3/C8 leicht verschoben, Bahnen teils neu. Korrigiert (korrekturen.py, DRC-geprueft):
    C8-Abstaende, GND15-Ende bei (113/21), Polaritaetsbalken der kleinen Elkos nicht mehr auf dem Pad.
    Fertigungsdaten, Ausdruck, Plots neu. DRC 0 Fehler, 0 offen.
    [TR-808PSU_Rev0.1-B_Cu.gbr, TR-808PSU_Rev0.1-B_Mask.gbr, TR-808PSU_Rev0.1-B_Silkscreen.gbr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]
2026-10-07 Kuehlkoerperbohrungen: 21,3 mm Abstand, mittig zu IC1, Q1, Q2
    Je Regler ein Paar symmetrisch zum mittleren Anschluss (vorher 22,6 bis 24,5 mm, nicht mittig).
    original_placement.py berechnet die Lage jetzt aus den Reglerpositionen. DRC 0 Fehler.
    [TR-808PSU_Rev0.1-B_Cu.gbr, TR-808PSU_Rev0.1-B_Mask.gbr, TR-808PSU_Rev0.1-B_Silkscreen.gbr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]
2026-10-07 Skripte unabhaengig vom Koordinatenursprung, Siebdruck/Ausdruck neu
    Die Platine wurde in KiCad verschoben (Umriss ab 19,84/20,65 mm): silk.py und ausdruck.py lesen den Umriss
    jetzt aus Edge.Cuts (platine.py); Namenskollision in silk.py behoben. Handergaenzungen (Bemassungen, Text)
    bleiben erhalten. Kuehlkoerperlochpaare 21,3 mm, mittig zu IC1/Q1/Q2.
    [TR-808PSU_Rev0.1-B_Cu.gbr, TR-808PSU_Rev0.1-B_Mask.gbr, TR-808PSU_Rev0.1-B_Silkscreen.gbr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]
2026-10-07 Schraubenloecher fuer IC1, Q1, Q2 (M3, H11-H13)
    Auf der Mittelachse der Regler, 1,9 mm ueber den Seitenloechern (Bestueckungsplan).
    Schaltplan mit 13 Befestigungsloechern, ERC 0, DRC 0 Fehler, Abgleich 0.
    [TR-808PSU_Rev0.1-B_Cu.gbr, TR-808PSU_Rev0.1-B_Mask.gbr, TR-808PSU_Rev0.1-B_Silkscreen.gbr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]
2026-10-07 Regler auf einer Hoehe, Bruecken W04
    IC1 auf die Hoehe von Q1/Q2 (y 47,135 mm), Bahnen ueber kurze Stuecke angebunden. D1/D2 als W04
    (Platine: 2W04G; Manual W-02). Schaltplan, Stueckliste, Gerber, Ausdruck neu. ERC 0, DRC 0 Fehler, Abgleich 0.
    [TR-808PSU_Rev0.1-B_Cu.gbr, TR-808PSU_Rev0.1-B_Mask.gbr, TR-808PSU_Rev0.1-B_Silkscreen.gbr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]
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2026-10-07 3D-Modell fuer die Sicherungshalter (Federclips mit 5x20-Sicherung)
    tools/pcb/modell_fuse.py erzeugt psu/TR808PSU.3dshapes/FuseClip_5x20_TF785.wrl, im Footprint und in der Platine eingebunden.
    3D-Ansichten neu.
    [TR-808PSU_Rev0.1.kicad_pcb]
2026-10-07 3D: Anschlussfahnen, liegende Regler
    Fahnenmodell (tools/pcb/modell_pin.py), je Seite nach aussen gedreht; IC1/Q1/Q2 als TO-220 Horizontal TabDown.
    modelle.py ordnet alles idempotent zu und laeuft am Ende von make.py. DRC unveraendert 0 Fehler.
    [TR-808PSU_Rev0.1.kicad_pcb]
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
